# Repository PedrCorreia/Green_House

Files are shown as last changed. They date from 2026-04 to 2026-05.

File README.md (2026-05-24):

# LoRaWAN Greenhouse Environmental Monitoring System

**Group 34346** — DTU IoT Project

Distributed IoT system for real-time greenhouse environmental monitoring using LoRa/LoRaWAN wireless communication over ESP32-based sensor nodes.

**Languages & Technologies:** C/C++ | Python | JavaScript | KiCad | Arduino

---

## System Overview

Multi-node greenhouse monitoring network with dual LoRa communication paths.

### Node Architecture
```
5 ESP32-based Nodes:
  • Sensor Node (LoRa P2P telemetry)
  • LoRaWAN Sensor Node (Cibicom OTAA uplink)
  • Gateway (WiFi/MQTT bridge + LoRa P2P RX)
  • Gateway Slave (LoRaWAN serial bridge)
  • Light Control Node (LoRa P2P receiver)
```

### Monitored Parameters
| Parameter | Sensor | Range |
|---|---|---|
| Temperature & Humidity | DHT22 | -40…+85°C, 0-100% |
| Soil Moisture | Capacitive | 0-100% |
| Light Intensity | KY-018 | 0-4095 lux |
| Battery Voltage | ADC | 0-5000 mV |

### Technology Stack
| Component | Technology |
|---|---|
| Microcontroller | ESP32 DevKit V1 |
| Radio Module | RN2483 LoRa |
| Power Management | AP2112K-3.3 LDO, AO3401A MOSFET |
| PCB Design | KiCad 10.0.0 |
| Communications | LoRa P2P, LoRaWAN (OTAA), WiFi, MQTT |

---

## Firmware Targets

| Target | Language | File | Purpose |
|---|---|---|---|
| Sensor Node | C++ | sensor-node.ino | DHT22/soil/light telemetry over LoRa P2P |
| LoRaWAN Sensor | C++ | lorawan-sensor-node.cpp | OTAA uplink to Cibicom/Loriot |
| Gateway | C++ | gateway.cpp | WiFi/MQTT bridge, LoRa P2P receiver |
| Gateway Slave | C++ | gateway-slave.cpp | LoRaWAN serial bridge |
| Light Node | C++ | light-node.ino | LoRa P2P command receiver for LED control |
| Backend Router | Python | loriot_router.py | 

---

## Communication Architecture

### Primary Path (LoRa P2P)
```
Sensor Node ──LoRa P2P──→ Gateway ──WiFi──→ MQTT Broker ──JSON──→ Dashboard
```

### Secondary Path (LoRaWAN)
```
LoRaWAN Sensor ──LoRaWAN──→ Cibicom/Loriot ──Webhook──→ Router ──MQTT──→ Dashboard
```
---

## Documentation

Individual README files in each directory contain hardware pinouts, configuration details, testing procedures, and troubleshooting.

**References:**
- [RN2483 Datasheet](https://ww1.microchip.com/downloads/en/DeviceDoc/40001811G.pdf)
- [ESP32 Arduino Core](https://github.com/espressif/arduino-esp32)
- [Cibicom LoRaWAN](https://iotnet.teracom.dk)
- [MQTT Protocol](https://mqtt.org)
- [Communication Flowchart](COMMUNICATION_FLOWCHART.md)
- [Hardware Schematics](hardware/)
- [Test Results](test/README.md)

---

**Last Updated:** May 2026 | **Status:** Ready for Submission | **Contact:** Group 34346

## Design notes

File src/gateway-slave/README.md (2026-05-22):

# ESP32 Gateway-Slave - LoRaWAN Cloud Bridge

## Table of Contents
1. [System Overview](#system-overview)
2. [Hardware Architecture](#hardware-architecture)
3. [Integration with Main Gateway](#integration-with-main-gateway)
4. [Data Structures](#data-structures)
5. [Execution Flow](#execution-flow)
6. [Methods Reference & Execution Order](#methods-reference--execution-order)
7. [Communication Protocols](#communication-protocols)
8. [Setup & Deployment](#setup--deployment)

---

## System Overview

### Purpose
The **Gateway-Slave** is an optional secondary ESP32 board that bridges LoRaWAN (cloud uplink) with the main gateway's P2P LoRa network. It acts as both:
1. **LoRaWAN relay**: Sends sensor data to Loriot/cloud backend
2. **P2P relay**: Forwards P2P LoRa packets back to main gateway via UART2

### Key Responsibilities
- **LoRaWAN Uplink**: Maintains persistent connection to Loriot cloud via OTAA join
- **Frequency Management**: Receives sleep/frequency commands from main gateway over UART2
- **P2P Passthrough**: Listens on same 868.1 MHz frequency as main network, forwards received packets to main gateway
- **Always-On Design**: Powered externally (USB), never sleeps; runs alongside main gateway

### When to Use
- **Extended range**: LoRaWAN coverage reaches areas P2P doesn't
- **Redundancy**: Sensor nodes can reach either gateway or relay through this one
- **Cloud uplinks**: Send data to Loriot, TTN, or other LoRaWAN network servers
- **Frequency monitoring**: Main gateway can command slave to change TX intervals from cloud

---

## Hardware Architecture

### Main Components

#### **ESP32 Microcontroller (Slave)**
- **Role**: Secondary control board dedicated to LoRaWAN
- **Power**: Externally powered (USB or AC adapter, does not sleep)
- **UART Ports**:
  - **UART1** (pins 16/17): Connected to RN2483 LoRaWAN module at 57600 baud
  - **UART2** (pins 18/19): Connected to main gateway for command/data bridge at 115200 baud
  - **UART0** (USB): USB Serial for debugging at 115200 baud

#### **RN2483 LoRa Module (Slave - LoRaWAN)**
- **Communication**: Connected via UART1 at 57600 baud
- **Protocol**: LoRaWAN Class A (OTAA join)
- **Network**: Loriot backend (cibicom.net) EU868 cluster
- **Purpose**: Cloud uplink for sensor data and downlink reception
- **Interface**: AT command protocol (via rn2xx3 library)
  - Commands: `sys get hweui`, `mac join otaa`, `mac tx ucnf`, etc.
  - Responses: `ok`, `accepted`, `mac_tx_ok`, `mac_rx <port> <hex>`, etc.

### Pin Mapping

```
ESP32 (Gateway-Slave) UART Connections:
├─ UART1 (LoRaWAN):
│  ├─ GPIO16 (RX) <- RN2483 TX
│  └─ GPIO17 (TX) -> RN2483 RX
├─ UART2 (Main Gateway Bridge):
│  ├─ GPIO18 (RX) <- Main Gateway GPIO19 (TX)
│  └─ GPIO19 (TX) -> Main Gateway GPIO18 (RX)
├─ GPIO23: RN2483 Reset (active-low)
├─ GPIO2: LED (status indicator)
└─ UART0 (USB Serial @ 115200):
   └─ Used for Serial.print() debugging

Baud Rates:
├─ UART1: 57600 (RN2483 standard for LoRaWAN)
├─ UART2: 115200 (slave bridge, higher speed for reliability)
└─ USB Serial: 115200 (debugging)
```

### Integration Point: Main Gateway ↔ Slave

```
Main Gateway GPIO19 (TX @ 115200)  →  Slave GPIO18 (RX)
Main Gateway GPIO18 (RX @ 115200)  ←  Slave GPIO17 (TX)

(Plus GND shared)
```

---

## Integration with Main Gateway

### Dual-Mode Operation

The slave simultaneously operates in two modes:

#### **Mode 1: LoRaWAN Class A Uplink (Primary)**
```
Slave RN2483 ← LoRaWAN network @ 868.1 MHz
    ↓
Joined to Loriot backend (OTAA credentials)
    ↓
Transmit 13-byte sensor payload on port 2
    ↓
Receive Class A downlink (1 sec after TX)
    ↓
Parse frequency/command, update sleep interval
    ↓
Acknowledge via UART2 to main gateway
```

#### **Mode 2: P2P Relay Passthrough (Secondary)**
```
Slave RN2483 also listens on 868.1 MHz in P2P mode
    ↓
Receives encrypted sensor packets from nodes
    ↓
Forward raw hex payload to main gateway via UART2
    ↓
Main gateway parses, validates, publishes to MQTT
```

### UART2 Command Protocol

**Main Gateway → Slave** (115200 baud, one command per line):
```
FREQ:<uint16>\n
  Example: "FREQ:120\n"
  Meaning: Set LoRaWAN TX interval to 120 seconds
  Response: "OK\n" or "ERR\n"

POLL\n
  Meaning: Send a poll uplink to receive queued downlinks
  Response: "OK\n" or "ERR\n"
```

**Slave → Main Gateway** (115200 baud):
```
<hex_payload>\n
  Example: "A5014947503030D2FFAA55...\n"
  Meaning: Forward P2P LoRa packet (13 bytes, hex encoded)
  Action: Main gateway parses as SensorData, publishes to MQTT

OK\n
  Meaning: Command (FREQ or POLL) was accepted

ERR\n
  Meaning: Join not established or TX failed
```

### Information Flow

```
MINUTE 0:00 ─ Main Gateway PING ────────────────────────
    ├─ Gateway: sendPing("scheduled")
    └─ Broadcast 8-byte PING on 868.1 MHz

MINUTE 0:00 ─ Slave Receives PING ──────────────────────
    ├─ Slave RN2483 in P2P RX mode
    ├─ Detects broadcast (P2P, not addressed)
    └─ (Ignores or logs for debugging)

MINUTE 0:04 ─ Slave Sends LoRaWAN Uplink ──────────────
    ├─ Slave: mac tx ucnf 2 <hex_payload>
    ├─ RN2483 transmits LoRaWAN packet to Loriot
    └─ Main gateway: sendToSlave("FREQ:118")
       ├─ Slave receives command via UART2
       ├─ Parses "FREQ:118"
       └─ Responds: "OK\n"

MINUTE 0:05 ─ Slave Receives Class A Downlink ─────────
    ├─ 1 second after LoRaWAN TX
    ├─ Loriot sends queued command (frequency update)
    ├─ Slave parses downlink port + payload
    └─ Slave responds to main gateway via UART2
       └─ Forwards parsed frequency if needed

MINUTE 2:00 ─ Cycle Repeats ────────────────────────────
    └─ Next PING / LoRaWAN TX
```

---

## Data Structures

### Sensor Data (13 bytes, from P2P relay)

**Received from gateway as hex string via UART2**:
```
<hex_payload>\n
Format: 26 hex characters = 13 bytes (same as main sensor-node format)

Structure:
Byte 0-3:   Device ID (0x01AABBCC for sensor nodes)
Byte 4-5:   Temperature (int16_t / 10)
Byte 6:     Humidity
Byte 7-8:   Lux
Byte 9-10:  Soil Moisture
Byte 11:    Water Leak
Byte 12:    Battery

Encryption: XOR with SHARED_KEY (same key as main gateway)
```

### LoRaWAN Uplink Packet

**13 bytes, port 2**:
```
[Device ID: 4B] [Temperature: 2B] [Humidity: 1B] [Lux: 2B] 
[Soil: 2B] [Leak: 1B] [Battery: 1B]

Encryption: LoRaWAN AppSKey + NwkSKey (hardware AES)
```

### LoRaWAN Downlink Packet (Class A)

**Received from Loriot, port varies**:
```
Port 2:  Frequency/sleep interval (2 bytes, big-endian)
  Example: [0x00, 0x78] = 120 seconds next TX interval
  
Custom Port: Other cloud commands as needed

Decryption: Automatic (RN2483 library handles LoRaWAN crypto)
```

### UART2 Command Packet

```
Command: "FREQ:<uint16>\n"
  Example: "FREQ:120\n" (11 bytes + newline)

Response: "OK\n" (3 bytes) or "ERR\n" (4 bytes)

Data Packet: "<hex_string>\n"
  Example: "A5014947503030D2FFAA55...\n" (27 bytes + newline)
```

---

## Execution Flow

### Boot Sequence

```
main() [Arduino startup]
  ↓
setup()
  ├─ Initialize Serial (115200 USB debug)
  ├─ Initialize GPIO (LED, reset pin)
  ├─ connectToLoRa()
  │  ├─ Reset RN2483 (GPIO23 pulse)
  │  ├─ Begin UART1 @ 57600 baud
  │  ├─ Get hardware EUI ("sys get hweui")
  │  └─ Print EUI to Serial (for Loriot registration)
  ├─ joinLoRaWAN()
  │  ├─ Set APPEUI and APPKEY (from code defines)
  │  ├─ Attempt "mac join otaa"
  │  ├─ Wait for acceptance (up to 10 seconds)
  │  └─ If success: set loraReady = true
  ├─ Initialize UART2 @ 115200 for main gateway bridge
  ├─ Initialize timing variables
  └─ Print "Slave ready"

[Loop begins]
```

### Main Loop (continuous)

```
loop() [runs thousands of times per second]
  ├─ readUart2FromGateway()
  │  └─ If line received:
  │     ├─ Check if "FREQ:<uint16>"
  │     │  ├─ Parse frequency/interval
  │     │  ├─ Update txIntervalMs
  │     │  └─ Respond: "OK\n"
  │     └─ Check if hex payload (P2P relay)
  │        ├─ Forward to main gateway later
  │        └─ Skip (main handles parsing)
  │
  ├─ readUart2PayloadsFromGateway()
  │  └─ Buffer P2P sensor packets for cloud uplink
  │
  ├─ manageLoRaWANTx()
  │  └─ If txIntervalMs elapsed:
  │     ├─ Build 13-byte payload
  │     ├─ Call sendLoRaData()
  │     │  ├─ mac tx ucnf 2 <hex>
  │     │  └─ Wait for "mac_tx_ok"
  │     └─ Listen for Class A downlink (1 sec)
  │        └─ readLoRaLine() to capture downlink
  │
  ├─ sendToGateway()
  │  └─ Forward P2P payloads to main gateway via UART2
  │
  └─ handleLed()
     └─ Blink LED to indicate activity
```

---

## Methods Reference & Execution Order

### **Phase 1: Initialization Functions** (called in `setup()`)

#### 1. `connectToLoRa()`
- **Purpose**: Initialize RN2483 LoRaWAN module with UART and reset
- **Called**: Once during setup
- **Parameters**: None
- **Flow**:
  1. Set GPIO23 (RN2483 reset pin) to HIGH
  2. Begin UART1 @ 57600 baud
  3. Pulse reset LOW → HIGH (hardware reset)
  4. Flush serial buffer
  5. Read banner from RN2483
  6. Get hardware EUI via "sys get hweui"
  7. Print EUI to Serial (user must register this on Loriot)
- **Returns**: void

#### 2. `joinLoRaWAN()`
- **Purpose**: Perform OTAA join to Loriot LoRaWAN network
- **Called**: Once during setup (critical for cloud uplink)
- **Parameters**: None
- **Flow**:
  1. Call rn2xx3 library to set APPEUI and APPKEY (from defines)
  2. Send "mac join otaa" command
  3. Wait for "accepted" response (up to 10 seconds)
  4. If joined: set loraReady = true, print success
  5. If timeout: print error, attempt retry in loop
- **Returns**: bool (true = joined, false = failed)
- **Critical**: Device must be registered on Loriot before join succeeds

---

### **Phase 2: Main Loop Functions** (called repeatedly in `loop()`)

#### 3. `readUart2FromGateway()`
- **Purpose**: Listen for commands from main gateway over UART2
- **Called**: Every loop iteration
- **Parameters**: None
- **Flow**:
  1. If slaveSerial.available():
     - Read line until '\n'
     - Check if "FREQ:<uint16>"
       - Parse interval, update txIntervalMs
       - Respond: "OK\n"
     - Else if hex string (P2P relay)
       - Buffer for later forwarding
- **Returns**: void

#### 4. `manageLoRaWANTx()`
- **Purpose**: Periodically send LoRaWAN uplinks at configured interval
- **Called**: Every loop iteration
- **Parameters**: None
- **Flow**:
  1. Check if txIntervalMs elapsed since lastTxMs
  2. If yes:
     - Build 13-byte sensor payload (or mock data)
     - Call sendLoRaData()
       - mac tx ucnf 2 <hex_payload>
       - Wait for "mac_tx_ok"
     - Update lastTxMs = millis()
     - Listen for Class A downlink (1 second window)
- **Returns**: void

#### 5. `sendLoRaData()`
- **Purpose**: Transmit LoRaWAN uplink packet
- **Called**: By manageLoRaWANTx()
- **Parameters**: None (uses global payload buffer)
- **Flow**:
  1. Convert payload to hex string
  2. Send command: "mac tx ucnf 2 <hex>"
  3. Wait for response (should be "ok" then "mac_tx_ok")
  4. Log to Serial
- **Returns**: bool (true = TX accepted, false = failed)

#### 6. `sendToGateway(const String& msg)`
- **Purpose**: Send data or acknowledgment back to main gateway over UART2
- **Called**: After processing commands or forwarding P2P packets
- **Parameters**: msg (response string)
- **Flow**:
  1. Print to slaveSerial
  2. Print newline
  3. Echo to Serial for debugging
- **Returns**: void

---

### **Phase 3: UART2 Bridge Functions**

#### 7. `handleSerialInput()`
- **Purpose**: Read commands from main gateway and process them
- **Called**: Every loop iteration
- **Parameters**: None
- **Flow**:
  1. While slaveSerial.available():
     - Read line until '\n'
     - Trim whitespace
     - Check if "FREQ:120" format
       - Extract uint16_t value
       - Update txIntervalMs
       - Respond "OK\n"
     - Else if hex string
       - Forward to gateway (or ignore if P2P relay)
- **Returns**: void

#### 8. `relayP2PPacket(const String& hexPayload)`
- **Purpose**: Forward P2P LoRa packet from slave's RN2483 back to main gateway
- **Called**: If slave RN2483 receives P2P packet while in RX mode
- **Parameters**: hexPayload (26-char hex string)
- **Flow**:
  1. Send to gateway via sendToGateway()
  2. Main gateway receives, parses as SensorData
  3. Main gateway publishes to MQTT
- **Returns**: void

---

### **Phase 4: LoRaWAN Management Functions**

#### 9. `readLoRaLine(int timeoutMs)`
- **Purpose**: Read one line of text from RN2483 (blocking until '\n' or timeout)
- **Called**: By sendLoRaData() and downlink listeners
- **Parameters**: timeoutMs (maximum time to wait)
- **Flow**:
  1. Initialize timer and empty String
  2. While millis() < timeout:
     - If loraSerial.available():
       - Read char
       - Skip '\r'
       - If '\n', trim and return
       - Else append to line
     - Delay 1ms
  3. If timeout, return whatever accumulated (possibly empty)
- **Returns**: String (one line of text, or empty if timeout)

#### 10. `flushLoRaInput()`
- **Purpose**: Clear any pending data in LoRa serial buffer
- **Called**: Before RX mode or after TX
- **Parameters**: None
- **Flow**:
  1. While loraSerial.available(): read and discard
- **Returns**: void

#### 11. `parseFrequencyCommand(const String& cmd)`
- **Purpose**: Extract uint16_t sleep interval from "FREQ:120" format
- **Called**: By handleSerialInput()
- **Parameters**: cmd (e.g., "FREQ:120")
- **Flow**:
  1. Find ':' delimiter
  2. Extract substring after ':'
  3. Convert to uint16_t
  4. Validate range (MIN_TX_INTERVAL_MS to MAX_TX_INTERVAL_MS)
  5. Return parsed value
- **Returns**: uint16_t (interval in seconds, or 0 if invalid)

---

### **Phase 5: Utility Functions**

#### 12. `bytesToHex(const uint8_t* data, size_t len)`
- **Purpose**: Convert byte array to hex string
- **Called**: By sendLoRaData()
- **Parameters**:
  - data: input byte array
  - len: number of bytes
- **Flow**:
  1. For each byte:
     - Convert high nibble to hex char
     - Convert low nibble to hex char
     - Append both to output String
  2. Return uppercase hex string
- **Returns**: String (hex representation)

#### 13. `hexToBytes(const String& hexStr, uint8_t* out, size_t outLen)`
- **Purpose**: Convert hex string to byte array
- **Called**: By payload parsing functions
- **Parameters**:
  - hexStr: hex string (e.g., "A5014947503030D2")
  - out: output byte array
  - outLen: size of output array
- **Flow**:
  1. Validate hexStr.length() == outLen * 2
  2. For each pair of hex chars:
     - Convert to nibbles (0-15)
     - Combine: byte = (high << 4) | low
  3. Return true if success
- **Returns**: bool

#### 14. `setLed(bool on)`
- **Purpose**: Turn slave LED on/off (GPIO2)
- **Called**: To indicate activity or status
- **Parameters**: on (true = LED on, false = LED off)
- **Flow**:
  1. digitalWrite(LED_PIN, on ? HIGH : LOW)
  2. Log to Serial
- **Returns**: void

---

## Communication Protocols

### UART1: RN2483 LoRaWAN Module (57600 baud)

#### LoRaWAN AT Command Format
```
Request (Slave → RN2483):
  <command>\r\n
  Example: "mac tx ucnf 2 A50149474F50\r\n"

Response (RN2483 → Slave):
  <response>\r\n
  Examples:
    "ok\r\n"           (command accepted)
    "accepted\r\n"     (join successful)
    "mac_tx_ok\r\n"    (TX complete)
    "mac_rx 2 A50149...\r\n"  (downlink received on port 2)
    "invalid_param\r\n" (error)
```

#### Common Commands
```
Initialization:
  sys get hweui           → Returns hardware EUI (register on Loriot)
  mac set deveui <id>     → Set device EUI (usually not needed for OTAA)
  
Credentials:
  mac set appeui <hex>    → Application EUI (16 hex chars)
  mac set appkey <hex>    → Application Key (32 hex chars)
  
OTAA Join:
  mac join otaa           → Initiate join request
  Response: "ok" (sent), later "accepted" or timeout
  
Transmission:
  mac tx ucnf 2 <hex>     → Send unconfirmed uplink on port 2
  mac tx cnf 2 <hex>      → Send confirmed uplink (waits for ACK)
  
  Response: "ok" (accepted), then:
    "mac_tx_ok"  (TX complete, uplink sent)
    or
    "mac_err"    (TX failed)
  
  1 second after TX: Class A receive window opens
    "mac_rx 2 <hex>"  (if downlink received)
    or (no downlink)
```

### UART2: Main Gateway Bridge (115200 baud)

#### Command Protocol
```
Main Gateway → Slave:
  <command>\n

  FREQ:<uint16>\n
    Example: "FREQ:120\n"
    Meaning: Set LoRaWAN TX interval to 120 seconds
    Response: "OK\n" or "ERR\n"

  POLL\n
    Meaning: Send a poll uplink (receive-only, no data)
    Response: "OK\n" or "ERR\n"

Slave → Main Gateway:
  <response>\n

  OK\n               Command acknowledged
  ERR\n              Error (join failed, TX failed, etc.)
  <hex_payload>\n    P2P relay packet (13 bytes, hex encoded)
                    Example: "A5014947503030D2FFAA55...\n"
```

#### Typical Exchange
```
Main → Slave: "FREQ:120\n"
Slave → Main: "OK\n"
[Later, LoRaWAN TX happens]
Slave → Main: "<hex_payload>\n" (if P2P packet received)
Main → Slave: "POLL\n"
Slave → Main: "OK\n"
```

---

## Setup & Deployment

### Prerequisites

#### Credentials from Loriot
1. **Register device on Loriot (iotnet.teracom.dk)**:
   - Select "OTAA" mode
   - Click "Generate all except DevEUI"
   - Copy APPEUI (16 hex chars)
   - Copy APPKEY (32 hex chars)

2. **Flash slave, retrieve hardware EUI from Serial Monitor**:
   ```
   Slave starting...
   RN2483 connected.
   Hardware EUI: 70B3D5xxxxxxxx
   [Copy this value]
   ```

3. **Enter Hardware EUI on Loriot**:
   - On device page, fill in Hardware EUI field
   - Device is now registered and ready to join

#### Libraries Required
```
Arduino IDE → Sketch → Include Library → Manage Libraries

Install:
  - rn2xx3 (by Ideetron) - LoRaWAN library
  - HardwareSerial (built-in)
  - Arduino core libraries
```

### Configuration

**File**: [gateway-slave/gateway-slave.cpp](gateway-slave.cpp) (lines 33-35)

```cpp
static const char* APPEUI = "0123456789ABCDEF";  // 16 hex chars from Loriot
static const char* APPKEY = "0123456789ABCDEF0123456789ABCDEF";  // 32 hex chars

#define DEFAULT_TX_INTERVAL_MS 30000UL  // 30 seconds between uplinks
```

### Flashing Procedure

```
Board: ESP32 Dev Module
Upload Speed: 921600
Port: COM[your device]
File: gateway-slave/gateway-slave.cpp
```

### Verification

**Serial Monitor Output** (115200 baud):
```
Slave starting...
RN2483 connected.
Hardware EUI: 70B3D5XXXXXXXX
Attempting LoRaWAN join...
[Waiting for "accepted"...]
LoRaWAN joined successfully!
Slave ready.
[Every 30 seconds]
Sending LoRaWAN uplink on port 2...
TX complete.
Listening for Class A downlink...
```

**Main Gateway Integration**:
```
Gateway Serial:
  <- Slave: OK
  <- Slave: A5014947503030D2FFAA55... (P2P relay)
  
Main gateway publishes to MQTT:
  {"type":"sensorData","deviceId":"0x01AABBCC",...}
```

---

## Summary

The **Gateway-Slave** extends the greenhouse monitoring system to cloud platforms by:

| Aspect | Detail |
|---|---|
| **Primary Role** | LoRaWAN uplink bridge to Loriot |
| **Secondary Role** | P2P relay for extended coverage |
| **Power** | Externally powered (always-on) |
| **Communication** | UART1 to RN2483, UART2 to main gateway |
| **Timing** | LoRaWAN TX every 30-3600 seconds (configurable) |
| **Security** | LoRaWAN AES encryption (automatic) |

**Key Functions**:
1. OTAA join to Loriot LoRaWAN network
2. Periodic uplink with 13-byte sensor data
3. Receive Class A downlinks (frequency/sleep updates)
4. Forward P2P packets from main network to cloud
5. UART2 bridge for gateway coordination

**Integration Points**:
- Main Gateway sends commands via UART2 ("FREQ:120\n")
- Slave sends acknowledgments ("OK\n")
- Slave forwards P2P packets for MQTT publication
- Slave's LoRaWAN uplinks provide redundant cloud connectivity

See [Main Gateway Documentation](../gateway/README.md) for system-wide architecture.

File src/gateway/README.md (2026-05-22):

# ESP32 Gateway - Comprehensive Technical Documentation

## Table of Contents
1. [System Overview](#system-overview)
2. [Hardware Architecture](#hardware-architecture)
3. [Integration with Other Nodes](#integration-with-other-nodes)
4. [Data Structures](#data-structures)
5. [Execution Flow](#execution-flow)
6. [Methods Reference & Execution Order](#methods-reference--execution-order)
7. [Communication Protocols](#communication-protocols)
8. [Security & Obfuscation](#security--obfuscation)

---

## System Overview

### Purpose
The **Gateway** is the central hub of the Greenhouse monitoring system. It sits on WiFi and MQTT, acting as a bridge between remote sensor nodes (communicating via LoRa P2P radio) and a cloud MQTT dashboard. It also manages a secondary board (gateway-slave) that handles LoRaWAN uplinks to cloud infrastructure.

### Key Responsibilities
- **WiFi/MQTT Connectivity**: Maintains persistent WiFi connection and MQTT broker link for dashboard communication
- **Sensor Pinging**: Periodically wakes sensor nodes via LoRa broadcast pings (every 2 minutes)
- **Data Reception**: Listens for sensor node replies containing environmental data (temperature, humidity, lux, soil moisture, water leak, battery)
- **MQTT Publishing**: Publishes received sensor data as JSON to the MQTT broker for dashboard visualization
- **Light Control**: Computes when plants need supplemental light based on ambient lux levels and sends control commands back to nodes
- **Slave Coordination**: Bridges commands and sensor data with a secondary gateway-slave board via UART2
- **Always-On Design**: Gateway never sleeps; it maintains 24/7 connectivity and is powered externally

---

## Hardware Architecture

### Main Components

#### **ESP32 Microcontroller (Main Gateway)**
- **Role**: Central control board with WiFi and MQTT stack
- **Power**: Externally powered (does not sleep)
- **UART Ports**:
  - **UART1** (pins 16/17): Connected to RN2483 LoRa module for P2P radio with sensor nodes
  - **UART2** (pins 18/19): Connected to gateway-slave ESP32 board
  - **UART0** (USB): USB Serial for debugging and manual testing

#### **RN2483 LoRa Module (Main Gateway)**
- **Communication**: Connected via UART1 at 57600 baud
- **Protocol**: LoRa P2P (not LoRaWAN)
- **Frequency**: 868.1 MHz (European ISM band)
- **Purpose**: Raw LoRa radio with sensor nodes using proprietary packet format
- **Interface**: AT command protocol
  - Commands: `radio tx`, `radio rx`, `radio set`, `mac pause`, `sys get ver`
  - Responses: `ok`, `radio_tx_ok`, `radio_rx <hex_payload>`, `radio_err`, etc.

#### **ESP32 Microcontroller (Gateway-Slave)**
- **Role**: Secondary board dedicated to LoRaWAN protocol
- **Connection**: UART2 bridge from main gateway (pins 18→16 RX, 19→17 TX)
- **Purpose**: Separate LoRaWAN stack for cloud uplinks; main gateway bridges frequency commands and receives parsed sensor data
- **Power**: Can sleep independently

#### **RN2483 LoRa Module (Gateway-Slave)**
- **Communication**: Connected via UART1 at 57600 baud
- **Protocol**: LoRaWAN (Class A)
- **Purpose**: Cloud bridge for deeper coverage using Loriot or similar LoRaWAN network

### Pin Mapping

```
ESP32 (Main Gateway) UART Connections:
├─ UART1 (LoRa P2P):
│  ├─ GPIO16 (RX) <- RN2483 TX
│  └─ GPIO17 (TX) -> RN2483 RX
├─ UART2 (Slave Bridge):
│  ├─ GPIO18 (RX) <- ESP32 Slave GPIO17 (TX)
│  └─ GPIO19 (TX) -> ESP32 Slave GPIO16 (RX)
├─ GPIO2: RN2483 Reset (active-low)
├─ GPIO4: LED (status indicator)
└─ UART0 (USB Serial @ 115200):
   └─ Used for Serial.print() debugging

Baud Rates:
├─ UART1: 57600 (RN2483 standard)
├─ UART2: 115200 (slave bridge, faster for reliability)
└─ USB Serial: 115200 (debugging)
```

---

## Integration with Other Nodes

### System Architecture Diagram

```
                          Internet / MQTT Broker (broker.emqx.io)
                                    ↑
                                    | WiFi + MQTT
                                    |
    ┌─────────────────────────────────────────────────────────┐
    │  ESP32 Gateway (Main Board)                             │
    │  ├─ WiFi (receives commands, publishes sensor data)     │
    │  ├─ MQTT (subscriptions: ping, control; topic: status) │
    │  ├─ UART1 ← RN2483 LoRa P2P (868.1 MHz)                │
    │  └─ UART2 ← Gateway-Slave (LoRaWAN bridge)             │
    └────┬────────────────────────────────┬──────────────────┘
         │ LoRa P2P @ 868.1 MHz           │ UART2 @ 115200
         │ (Proprietary protocol)         │
         │                                │
    ┌────▼──────────────────┐      ┌────▼──────────────────────┐
    │ Sensor Nodes          │      │ ESP32 Gateway-Slave       │
    │ (Multiple instances)  │      │ ├─ LoRaWAN Class A        │
    │ ├─ Node 0x01AABBCC   │      │ ├─ RN2483 LoRaWAN         │
    │ ├─ Node 0x02CCDDEE   │      │ ├─ Loriot Cloud Bridge    │
    │ └─ ...                │      │ └─ Receives sleep/freq cmds│
    └───────────────────────┘      └───────────────────────────┘
           ↑                               ↑
           │ 13-byte encrypted            │ LoRaWAN
           │ sensor payloads              │ Uplink
           │                              │
```

### Sensor Node Integration

#### **Wake-Up Flow**
1. **Scheduled Ping** (every 2 minutes):
   - Gateway sends 8-byte broadcast PING packet (`0x50 0x49 0x4E 0x47` + 4-byte SHARED_KEY)
   - Encrypted with XOR to prevent rogue nodes

2. **Node Reception**:
   - Sensor node's RN2483 receives the ping
   - Node wakes from sleep upon radio interrupt
   - Node checks packet validity (XOR obfuscation)

3. **Sensor Data TX**:
   - Node collects temperature, humidity, lux, soil moisture, water leak, battery voltage
   - Packages into 13-byte binary struct, XOR encrypts with SHARED_KEY
   - Transmits 26-char hex string via LoRa back to gateway within ~3 seconds (BOOT_OVERHEAD_MS)

#### **Data Reception Flow**
1. **Post-Ping Listen Window** (10 seconds):
   - Gateway enters RX mode after transmitting ping
   - Listens for `radio_rx <hex>` response from RN2483

2. **Payload Parsing**:
   - Convert 26-char hex string to 13 bytes
   - XOR decrypt with SHARED_KEY
   - Extract device ID (4 bytes), temperature (2 bytes, /10), humidity, lux, soil moisture, water leak, battery

3. **Validation**:
   - Verify device ID is in APPROVED_DEVICE_IDS whitelist
   - Reject if unknown node (security & noise filtering)

4. **MQTT Publication**:
   - JSON format: `{"type":"sensorData", "deviceId":"0x01AABBCC", "temperature":23.5, "humidity":65, "lux":150, ...}`
   - Published to `esp32/myroom123/status`

#### **Light Control Flow**
1. **Lux Threshold Check**:
   - If received lux < 200 (LIGHT_THRESHOLD_LUX), plant needs light
   - If lux >= 200, light is adequate

2. **Send Light Command**:
   - If light needed: send 8-byte command to sensor node with `desiredLux=500`, `nextSleepSeconds` (calculated)
   - If light adequate: send sync-only command (no supplemental light)

3. **Node Response**:
   - Node receives command, schedules next wake-up time
   - Sensor node stays awake longer if lux control active
   - Sensor node calculates new sleep interval

### Gateway-Slave Integration (LoRaWAN Bridge)

#### **Slave Communication Protocol (UART2)**
```
Main Gateway ← UART2 → Gateway-Slave
Baud: 115200, Format: 8N1

Command Format (Main → Slave):
  "FREQ:<uint16>\n"      - Set LoRaWAN TX frequency (e.g., "FREQ:120\n")
  "SLEEP:<seconds>\n"    - Command sleep duration

Response Format (Slave → Main):
  "<hex_payload>\n"      - Forward received sensor data as hex string
  "ACK\n"                - Command acknowledged
  "ERR\n"                - Error response
```

#### **Slave Data Flow**
1. **Main gateway sends frequency command**:
   - Example: `sendToSlave("FREQ:120")` instructs slave to transmit LoRaWAN uplink on frequency 120
   - Slave receives command, updates LoRaWAN parameters, transmits uplink to cloud

2. **Slave forwards sensor data**:
   - If slave's RN2483 receives a LoRa P2P packet (same frequency, compatible modulation)
   - Slave forwards raw hex payload to main gateway via UART2
   - Main gateway parses as SensorData, publishes to MQTT (same as direct reception)
   - This allows extended coverage: sensors can talk to either gateway or relay through slave

---

## Data Structures

### SensorData (13 bytes)

```cpp
struct SensorData {
  uint32_t deviceId;      // 4 bytes: Unique sensor node identifier
  float    temperature;   // 2 bytes: Signed int16, divided by 10 (e.g., 235 = 23.5°C)
  uint8_t  humidity;      // 1 byte: 0-100%
  uint16_t lux;           // 2 bytes: Ambient light level (0-65535 lux)
  uint16_t soilMoisture;  // 2 bytes: Capacitive soil moisture reading
  bool     waterLeak;     // 1 byte: Boolean flag (any non-zero = true)
  uint8_t  battery;       // 1 byte: Battery percentage or raw ADC value (0-255)
};
```

**Binary Layout**:
```
Byte 0-3:  Device ID (big-endian uint32_t)
Byte 4-5:  Temperature (big-endian int16_t, /10)
Byte 6:    Humidity
Byte 7-8:  Lux (big-endian uint16_t)
Byte 9-10: Soil Moisture (big-endian uint16_t)
Byte 11:   Water Leak
Byte 12:   Battery
```

### PING Packet (8 bytes)

```cpp
uint8_t pingBuf[8] = {
  0x50, 0x49, 0x4E, 0x47,  // ASCII "PING" (header)
  0xA3, 0x7F, 0x2C, 0x91   // SHARED_KEY (obfuscation)
};
```

Before TX: XOR encrypted with SHARED_KEY (cycles: key[0], key[1], key[2], key[3], key[0]...)

### Light Command Packet (8 bytes)

```cpp
uint8_t lightCmd[8] = {
  // Byte 0-3: Target device ID (big-endian uint32_t)
  // Byte 4-5: Desired lux level (big-endian uint16_t, 0 if not needed)
  // Byte 6-7: Next sleep interval in seconds (big-endian uint16_t)
};
```

Before TX: XOR encrypted with SHARED_KEY

### Light Control Node Packet (5 bytes)

```cpp
uint8_t lightNodeCmd[5] = {
  // Byte 0-3: Light node device ID (e.g., 0x00000005)
  // Byte 4: Command (0x01 = ON, 0x00 = OFF)
};
```

Response (ACK): Same format with status in byte 4 (0x01 = OK, 0x00 = FAIL)

---

## Execution Flow

### Boot Sequence

```
main() [Arduino startup]
  ↓
setup()
  ├─ Initialize Serial (115200)
  ├─ Initialize GPIO (LED pin)
  ├─ connectToWiFi()
  │  ├─ WiFi.mode(WIFI_STA)
  │  ├─ WiFi.begin(SSID, PASSWORD)
  │  └─ Wait for connection (20 sec timeout)
  ├─ Initialize MQTT client
  │  ├─ setServer(broker.emqx.io, 1883)
  │  └─ setCallback(mqttCallback)
  ├─ initLoRa()
  │  ├─ Reset RN2483 (GPIO2)
  │  ├─ Begin UART1 @ 57600
  │  ├─ Get RN2483 version ("sys get ver")
  │  ├─ Pause MAC ("mac pause") to enable raw P2P mode
  │  └─ Configure 13 radio parameters (freq, SF, BW, power, CRC, etc.)
  ├─ Initialize Slave UART2 @ 115200
  ├─ Initialize timing variables (lastPingTime, lastHeartbeatTime)
  └─ Print "Gateway ready"

[Loop begins]
```

### Main Loop (runs every ~1-10ms)

```
loop() [continuous, called thousands of times per second]
  ├─ ensureWiFiConnected()
  │  └─ If disconnected, attempt WiFi.begin() every 5 sec
  ├─ If WiFi connected:
  │  ├─ If MQTT disconnected:
  │  │  └─ Retry MQTT every 3 sec (connectToMQTT)
  │  │     ├─ Connect to broker
  │  │     └─ Subscribe to topics (control, ping)
  │  └─ If MQTT connected:
  │     ├─ mqttClient.loop() [process incoming messages]
  │     └─ If 60 sec elapsed (HEARTBEAT_INTERVAL_MS):
  │        └─ publishHeartbeat() [send "Hello" + uptime to MQTT]
  ├─ If 120 sec elapsed (PING_INTERVAL_MS):
  │  └─ sendPing("scheduled") [wake all sensor nodes]
  ├─ handleSerialLightControlInput()
  │  └─ If USB Serial: '1' = turn on light, '0' = turn off (test shortcut)
  └─ handleSlaveSerial()
     └─ Read any responses from slave, parse & publish to MQTT
```

---

## Methods Reference & Execution Order

### **Phase 1: Initialization Functions** (called in `setup()`)

#### 1. `connectToWiFi()`
- **Purpose**: Establish initial WiFi connection
- **Called**: Once during setup
- **Parameters**: None (reads WIFI_SSID, WIFI_PASSWORD defines)
- **Flow**:
  1. Set WiFi mode to STA (Station)
  2. Call WiFi.begin() with credentials
  3. Wait up to 20 seconds for connection
  4. Print IP address if successful, or retry message
- **Returns**: void (no return value; uses global WiFi state)

#### 2. `initLoRa()`
- **Purpose**: Initialize RN2483 LoRa module with all radio parameters
- **Called**: Once during setup (critical; halts if fails)
- **Parameters**: None
- **Flow**:
  1. Set GPIO2 (RN2483 reset pin) to HIGH
  2. Begin UART1 @ 57600 baud
  3. Pulse reset low → high (hardware reset)
  4. Flush any stale serial data
  5. Read banner message from RN2483
  6. Get module version ("sys get ver")
  7. Send "mac pause" to disable LoRaWAN MAC
  8. Send 13 radio configuration commands:
     - `radio set mod lora` (mode)
     - `radio set freq 868100000` (frequency)
     - `radio set pwr 14` (transmit power)
     - `radio set sf sf12` (spreading factor)
     - `radio set afcbw 41.7` (AFC bandwidth)
     - `radio set rxbw 125` (RX bandwidth)
     - `radio set prlen 8` (preamble length)
     - `radio set crc on` (CRC enable)
     - `radio set iqi off` (IQ inversion)
     - `radio set cr 4/5` (coding rate)
     - `radio set wdt 60000` (watchdog timeout)
     - `radio set sync 12` (sync word)
     - `radio set bw 125` (bandwidth again)
  9. Return true if all commands return "ok", else false
- **Returns**: bool (true = ready, false = failed)
- **Critical**: If false, gateway halts (safety measure; broken radio means system cannot wake nodes)

---

### **Phase 2: Main Loop Functions** (called repeatedly in `loop()`)

#### 3. `ensureWiFiConnected()`
- **Purpose**: Maintain WiFi connection; retry if dropped
- **Called**: Every loop iteration
- **Parameters**: None
- **Flow**:
  1. Check WiFi.status() == WL_CONNECTED
  2. If connected, return immediately (no action)
  3. If disconnected and 5 sec elapsed since last retry:
     - Print "WiFi dropped"
     - Call WiFi.disconnect() then WiFi.begin() again
- **Returns**: void (no return; modifies global WiFi state)
- **Note**: Non-blocking; doesn't wait for connection

#### 4. `mqttClient.loop()`
- **Purpose**: Process incoming MQTT messages
- **Called**: Every loop iteration (if WiFi + MQTT connected)
- **Parameters**: None (calls registered callback)
- **Triggers**: mqttCallback() for messages on subscribed topics
- **Returns**: void

#### 5. `publishHeartbeat()`
- **Purpose**: Periodically send gateway status to MQTT (keep-alive)
- **Called**: Every 60 seconds (HEARTBEAT_INTERVAL_MS)
- **Parameters**: None
- **Flow**:
  1. Check if MQTT connected (safety check)
  2. Build JSON: "Hello from ESP32 | uptime: X | LED: ON/OFF"
  3. Publish to TOPIC_STATUS ("esp32/myroom123/status")
  4. Print to Serial
- **Returns**: void

#### 6. `handleSerialLightControlInput()`
- **Purpose**: Read manual light control commands from USB Serial (test shortcut)
- **Called**: Every loop iteration
- **Parameters**: None
- **Flow**:
  1. If Serial.available():
     - Read one character
     - If '1': sendLightControlCmd(true)
     - If '0': sendLightControlCmd(false)
- **Returns**: void
- **Note**: For testing only; remove when automatic light control verified

#### 7. `handleSlaveSerial()`
- **Purpose**: Read responses/data from gateway-slave over UART2
- **Called**: Every loop iteration
- **Parameters**: None
- **Flow**:
  1. While slaveSerial.available():
     - Read line until '\n'
     - Trim whitespace
     - Parse as hex payload
     - Call parseSensorPayload()
     - If valid, call publishSensorData() to MQTT
- **Returns**: void

---

### **Phase 3: WiFi/MQTT Functions** (event-driven, called from loop or callbacks)

#### 8. `connectToMQTT()`
- **Purpose**: Connect to MQTT broker and subscribe to topics
- **Called**: When MQTT disconnected and reconnect interval elapsed
- **Parameters**: None
- **Flow**:
  1. Check WiFi connected (safety check)
  2. Build unique client ID from ESP32 MAC address
  3. Call mqttClient.connect(clientId)
  4. If connected:
     - Subscribe to TOPIC_CONTROL ("esp32/myroom123/control")
     - Subscribe to TOPIC_PING ("esp32/myroom123/ping")
     - Publish connection message to TOPIC_STATUS
     - Return true
  5. If failed, print error code and return false
- **Returns**: bool (true = connected, false = failed)

#### 9. `mqttCallback(char* topic, byte* payload, unsigned int length)`
- **Purpose**: Handle incoming MQTT messages
- **Called**: Automatically by mqttClient.loop() when message arrives
- **Parameters**:
  - topic: string (e.g., "esp32/myroom123/ping")
  - payload: byte array (raw message data)
  - length: size of payload
- **Flow**:
  1. Convert payload bytes to String
  2. Print topic and message to Serial
  3. Check topic:
     - If TOPIC_PING ("esp32/myroom123/ping"):
       - If msg == "PING": call manualPingWithRetry()
       - Publish result to MQTT
     - If TOPIC_CONTROL ("esp32/myroom123/control"):
       - If msg == "ON" or "LIGHT ON": setLed(true), sendLightControlCmd(true)
       - If msg == "OFF" or "LIGHT OFF": setLed(false), sendLightControlCmd(false)
- **Returns**: void

#### 10. `publishStatus(const String& msg)`
- **Purpose**: Log status to Serial and publish to MQTT
- **Called**: From various functions (error/info reporting)
- **Parameters**: msg (status message string)
- **Flow**:
  1. Print to Serial ("STATUS: " + msg)
  2. If MQTT connected, publish to TOPIC_STATUS
- **Returns**: void

#### 11. `publishLightControlState()`
- **Purpose**: Publish current LED state to MQTT as JSON
- **Called**: When light state changes (sendLightControlCmd)
- **Parameters**: None
- **Flow**:
  1. Build JSON: `{"type":"LED", "deviceId":"0x00000005", "state":"ON"/"OFF"}`
  2. Print to Serial
  3. Publish to TOPIC_STATUS
- **Returns**: void

#### 12. `setLed(bool on)`
- **Purpose**: Turn gateway LED on/off (physical GPIO4 and state variable)
- **Called**: From mqttCallback or manual input
- **Parameters**: on (true = LED on, false = LED off)
- **Flow**:
  1. Set ledState variable
  2. digitalWrite(LED_PIN, on ? HIGH : LOW)
  3. Print status to Serial
- **Returns**: void

---

### **Phase 4: Slave Communication Functions**

#### 13. `sendToSlave(const String& cmd)`
- **Purpose**: Send command to gateway-slave board over UART2
- **Called**: When main gateway needs to instruct slave (e.g., frequency updates)
- **Parameters**: cmd (command string, e.g., "FREQ:120")
- **Flow**:
  1. Print command to slaveSerial
  2. Print newline
  3. Echo to Serial for debugging
- **Returns**: void

#### 14. `handleSlaveSerial()` (duplicate listing for reference)
- **See Phase 2, Function 7**

---

### **Phase 5: LoRa Radio Communication Functions**

#### 15. `sendLoRaCommand(const String& cmd, int timeoutMs)`
- **Purpose**: Send AT command to RN2483 and read response
- **Called**: During initLoRa() and when TX/RX packets
- **Parameters**:
  - cmd: AT command (e.g., "radio tx A50149474F50")
  - timeoutMs: how long to wait for response
- **Flow**:
  1. Print command to loraSerial
  2. Send "\r\n" terminator
  3. Call readLoRaLine(timeoutMs) to read response
  4. Print response to Serial
  5. Return response string
- **Returns**: String (response from RN2483)

#### 16. `readLoRaLine(int timeoutMs)`
- **Purpose**: Read one line of text from RN2483 (blocking until '\n' or timeout)
- **Called**: By sendLoRaCommand() and waitForSensorReply()
- **Parameters**: timeoutMs (maximum time to wait)
- **Flow**:
  1. Initialize timer and empty String
  2. While millis() < timeout:
     - If loraSerial.available():
       - Read char
       - Skip '\r' (carriage return)
       - If '\n', trim and return line
       - Else append to line
     - Delay 1ms (yield)
  3. If timeout, trim and return whatever accumulated (possibly empty)
- **Returns**: String (one line of text, or empty if timeout)

#### 17. `flushLoRaInput()`
- **Purpose**: Clear any pending data in LoRa serial buffer
- **Called**: During initLoRa() and before RX mode
- **Parameters**: None
- **Flow**:
  1. While loraSerial.available(): read and discard
- **Returns**: void

#### 18. `stopRx()`
- **Purpose**: Stop active RX listening on LoRa radio
- **Called**: If RX times out or error detected
- **Parameters**: None
- **Flow**:
  1. Send "radio rxstop\r\n" to RN2483
  2. Read up to 2 lines of response (drain buffer)
  3. Print to Serial
- **Returns**: void

---

### **Phase 6: Sensor Ping & Communication Functions** (core data flow)

#### 19. `sendPing(const char* reason)` 🎯 **CRITICAL**
- **Purpose**: Broadcast wake-up PING to all sensor nodes
- **Called**: Every 120 seconds (PING_INTERVAL_MS) or manually from MQTT
- **Parameters**: reason (string for logging, e.g., "scheduled" or "manual MQTT retry")
- **Flow**:
  1. Check loraReady (safety check)
  2. Build 8-byte PING packet: 0x50494E47 (ASCII "PING") + SHARED_KEY (4 bytes)
  3. Call bytesToHex() to convert to 26-char hex string
  4. Send command: "radio tx [hex]"
  5. Read response (should be "ok")
  6. If not "ok", log and return false
  7. Wait for "radio_tx_ok" (confirms TX complete, ~1-5 sec)
  8. Call waitForSensorReply(POST_PING_WAIT_MS = 10 sec)
  9. Return true if reply received, false if timeout/error
- **Returns**: bool (true = at least one sensor replied)

#### 20. `manualPingWithRetry()` 🎯 **CRITICAL**
- **Purpose**: Retry PING sequence when manually triggered via MQTT
- **Called**: From mqttCallback when "PING" message received on TOPIC_PING
- **Parameters**: None
- **Flow**:
  1. Save original lastPingTime (to restore if all retries fail)
  2. Loop for up to MANUAL_PING_TIMEOUT_MS (150 sec total):
     - Call sendPing("manual MQTT retry")
     - If success, return true immediately
     - If failed, wait RETRY_INTERVAL_MS (15 sec) before next attempt
     - Repeat
  3. If timeout reached, restore original lastPingTime and return false
- **Returns**: bool (true = got reply within 150 sec, false = all retries expired)

#### 21. `waitForSensorReply(int timeoutMs)` 🎯 **CRITICAL**
- **Purpose**: Enter RX mode and listen for sensor node reply
- **Called**: By sendPing() after broadcasting PING
- **Parameters**: timeoutMs (listen window, typically 10 sec)
- **Flow**:
  1. Send "radio rx 0" command (0 = listen until packet or watchdog)
  2. If not "ok", return false
  3. Call readLoRaLine(timeoutMs) to wait for response
  4. Check response:
     - If "radio_rx [hex]":
       - Extract hex payload
       - Convert hex string to 13 bytes (hexToBytes)
       - XOR decrypt with SHARED_KEY (xorWithKey)
       - Parse into SensorData struct (parseSensorPayload)
       - Validate device ID in whitelist (isApprovedDevice)
       - If invalid, reject and return false
       - If valid:
         - Calculate if light needed (lux < 200?)
         - Calculate nextSleepSeconds
         - Call publishSensorData() to MQTT
         - Delay LIGHT_CMD_PRE_DELAY_MS (400ms) for RX turnaround
         - Call sendLightCommand() to transmit control packet
         - Call sendLightControlCmd() to turn light on/off if needed
         - Return true
     - If "radio_err" or timeout: return false
- **Returns**: bool (true = valid sensor reply processed, false = no valid reply)

#### 22. `parseSensorPayload(const String& hexStr, SensorData& out)`
- **Purpose**: Decode 26-char hex string to 13-byte SensorData struct
- **Called**: By waitForSensorReply() and handleSlaveSerial()
- **Parameters**:
  - hexStr: 26 hex characters (13 bytes)
  - out: reference to SensorData struct (output)
- **Flow**:
  1. Validate hex string length (must be 26 chars)
  2. Call hexToBytes() to convert hex to binary
  3. Extract fields (big-endian):
     - Bytes 0-3: deviceId (uint32_t)
     - Bytes 4-5: temperature as int16_t, divide by 10 → float
     - Byte 6: humidity
     - Bytes 7-8: lux
     - Bytes 9-10: soilMoisture
     - Byte 11: waterLeak (non-zero = true)
     - Byte 12: battery
  4. Return true if success, false if parse error
- **Returns**: bool (true = valid payload, false = malformed)

#### 23. `publishSensorData(const SensorData& d, bool needsLight)`
- **Purpose**: Format sensor data as JSON and publish to MQTT
- **Called**: By waitForSensorReply() and handleSlaveSerial()
- **Parameters**:
  - d: SensorData struct with all readings
  - needsLight: boolean indicating if lux below threshold
- **Flow**:
  1. Build JSON object:
     ```json
     {
       "type": "sensorData",
       "deviceId": "0x01AABBCC",
       "temperature": 23.5,
       "humidity": 65,
       "lux": 150,
       "soilMoisture": 512,
       "waterLeak": false,
       "battery": 95,
       "needsLight": true
     }
     ```
  2. Print to Serial
  3. If MQTT connected, publish to TOPIC_STATUS
- **Returns**: void

#### 24. `calculateNextSleepSeconds()` ⏰
- **Purpose**: Compute next sleep interval for sensor node
- **Called**: By waitForSensorReply() before sending light command
- **Parameters**: None (uses global lastPingTime and millis())
- **Flow**:
  1. Calculate time to next ping: (lastPingTime + PING_INTERVAL_MS) - millis()
  2. Subtract BOOT_OVERHEAD_MS (3 sec for node to boot)
  3. Convert to seconds
  4. Clamp to MIN_SLEEP_S (10) and MAX_SLEEP_S (65000)
  5. Log calculated value to Serial
  6. Return as uint16_t
- **Returns**: uint16_t (sleep seconds)

---

### **Phase 7: Light Control Functions**

#### 25. `sendLightCommand(uint32_t targetDeviceId, uint16_t desiredLux, uint16_t nextSleepS)`
- **Purpose**: Send 8-byte control packet to sensor node with lux target and sleep interval
- **Called**: By waitForSensorReply() after receiving sensor data
- **Parameters**:
  - targetDeviceId: device ID of sensor node (e.g., 0x01AABBCC)
  - desiredLux: target lux level (0 if no light needed, 500 if needed)
  - nextSleepS: next sleep interval in seconds
- **Flow**:
  1. Check loraReady
  2. Build 8-byte packet (big-endian):
     - Bytes 0-3: targetDeviceId
     - Bytes 4-5: desiredLux
     - Bytes 6-7: nextSleepS
  3. XOR encrypt with SHARED_KEY
  4. Convert to 16-char hex string
  5. Send "radio tx [hex]"
  6. Wait for "radio_tx_ok"
  7. Log packet details to Serial
  8. Return true if TX successful, false if failed
- **Returns**: bool

#### 26. `sendLightControlCmd(bool turnOn)` 💡
- **Purpose**: Send ON/OFF command to light node (device 0x00000005)
- **Called**: By mqttCallback (MQTT control) or handleSerialLightControlInput (manual test)
- **Parameters**: turnOn (true = ON, false = OFF)
- **Flow**:
  1. Check loraReady
  2. Retry up to maxRetries (currently 1)
  3. Build packet with light node device ID (0x00000005) and command (0x01 for ON, 0x00 for OFF)
  4. Send "radio tx [hex]"
  5. Call waitForLightAck(turnOn) to verify ACK received
  6. If ACK OK, call publishLightControlState()
  7. If failed, retry
  8. Return true if at least one retry succeeded
- **Returns**: bool

#### 27. `waitForLightAck(bool turnOn)` 🔄
- **Purpose**: Wait for light node to acknowledge command
- **Called**: By sendLightControlCmd()
- **Parameters**: turnOn (whether this was ON or OFF command)
- **Flow**:
  1. Enter RX mode ("radio rx 0")
  2. Wait ACK_TIMEOUT_MS (5 sec) for "radio_rx [hex]" response
  3. Decode response:
     - If device ID matches light node (0x00000005)
     - If status byte is 0x01: ACK OK (return 1)
     - If status byte is 0x00: ACK FAIL (return 0)
  4. If timeout or error: return -1
- **Returns**: int (1 = OK, 0 = FAIL, -1 = TIMEOUT)

---

### **Phase 8: Utility Functions**

#### 28. `makeDevicePacket(uint32_t deviceId, uint8_t value)`
- **Purpose**: Create 5-byte device ID + value packet, XOR encrypt, return as hex string
- **Called**: By sendLightControlCmd()
- **Parameters**:
  - deviceId: target device (e.g., 0x00000005 for light node)
  - value: command byte (0x00 = OFF, 0x01 = ON)
- **Flow**:
  1. Build 5-byte buffer: [ID high, ID mid-high, ID mid-low, ID low, value]
  2. XOR encrypt with SHARED_KEY
  3. Convert to 10-char hex string
  4. Return
- **Returns**: String (10-char hex)

#### 29. `hexToBytes(const String& hexStr, uint8_t* out, size_t outLen)`
- **Purpose**: Convert hex string to byte array
- **Called**: By parseSensorPayload(), waitForSensorReply()
- **Parameters**:
  - hexStr: hex string (e.g., "A50149474F50")
  - out: output byte array
  - outLen: size of output array
- **Flow**:
  1. Validate hexStr.length() == outLen * 2
  2. For each pair of hex chars:
     - Call hexNibble() to convert each char to 0-15
     - Combine: byte = (high nibble << 4) | low nibble
  3. Return true if success, false if format error
- **Returns**: bool

#### 30. `bytesToHex(const uint8_t* data, size_t len)`
- **Purpose**: Convert byte array to hex string
- **Called**: By sendPing(), sendLightCommand(), makeDevicePacket()
- **Parameters**:
  - data: input byte array
  - len: number of bytes
- **Flow**:
  1. For each byte:
     - Convert high nibble (0-15) to hex char ('0'-'9', 'A'-'F')
     - Convert low nibble to hex char
     - Append both to output String
  2. Return uppercase hex string
- **Returns**: String (hex representation)

#### 31. `hexNibble(char c)`
- **Purpose**: Convert single hex character ('0'-'9', 'a'-'f', 'A'-'F') to value (0-15)
- **Called**: By hexToBytes()
- **Parameters**: c (single hex character)
- **Flow**:
  1. If c >= '0' && c <= '9': return c - '0'
  2. If c >= 'a' && c <= 'f': return c - 'a' + 10
  3. If c >= 'A' && c <= 'F': return c - 'A' + 10
  4. Else: return -1 (error)
- **Returns**: int (0-15, or -1 for invalid)

#### 32. `xorWithKey(uint8_t* data, size_t len)`
- **Purpose**: XOR encrypt/decrypt data with SHARED_KEY (cycles through 4-byte key)
- **Called**: By sendPing(), waitForSensorReply(), sendLightCommand(), makeDevicePacket()
- **Parameters**:
  - data: byte array to encrypt/decrypt (modified in place)
  - len: length of data
- **Flow**:
  1. For each byte at index i:
     - data[i] ^= SHARED_KEY[i % 4]
  2. (XOR is reversible: apply twice to get original)
- **Returns**: void (modifies data in place)

#### 33. `isApprovedDevice(uint32_t id)` 🔐
- **Purpose**: Check if device ID is in whitelist of approved sensor nodes
- **Called**: By waitForSensorReply() to validate received device ID
- **Parameters**: id (device ID to check)
- **Flow**:
  1. Loop through APPROVED_DEVICE_IDS array
  2. If id matches any entry, return true
  3. If no match found, return false
- **Returns**: bool (true = approved, false = rogue/unknown node)

---

## Communication Protocols

### UART1: RN2483 LoRa Module (57600 baud)

#### AT Command Format
```
Request (Gateway → RN2483):
  <command>\r\n
  Example: "radio tx A50149474F50\r\n"

Response (RN2483 → Gateway):
  <response>\r\n
  Examples:
    "ok\r\n"
    "radio_tx_ok\r\n"
    "radio_rx A501494D4F50\r\n"
    "radio_err\r\n"
    "invalid_param\r\n"
```

#### Common Commands
```
Initialization:
  sys get ver              → Returns RN2483 firmware version
  mac pause                → Disable LoRaWAN MAC, enable raw LoRa P2P
  
Radio Configuration:
  radio set freq 868100000 → Set frequency
  radio set sf sf12        → Set spreading factor
  radio set pwr 14         → Set TX power
  radio set crc on         → Enable CRC
  
Transmission:
  radio tx <hex_payload>   → Transmit packet (hex string)
  Response: "ok" (accepted), then "radio_tx_ok" (completed)
  
Reception:
  radio rx 0               → Listen until packet or watchdog
  Response: "radio_rx <hex_payload>" (packet received)
           or "radio_err" (timeout/error)
  
  radio rxstop             → Stop RX mode
  Response: "ok"
```

### UART2: Gateway-Slave Bridge (115200 baud)

#### Command Protocol
```
Main Gateway → Slave:
  <command>\n
  Examples:
    "FREQ:120\n"     - Set LoRaWAN TX frequency
    "SLEEP:3600\n"   - Set sleep duration

Slave → Main Gateway:
  <hex_payload>\n   - Forward received sensor data
  "ACK\n"           - Command acknowledged
  "ERR\n"           - Error
```

### MQTT Protocol

#### Topics

**Subscriptions (gateway receives)**:
- `esp32/myroom123/ping`: Send "PING" to trigger manual wake-up sequence
- `esp32/myroom123/control`: Send "ON"/"OFF" or "LIGHT_ON"/"LIGHT_OFF" to control LED

**Publications (gateway sends)**:
- `esp32/myroom123/status`: All outgoing messages (heartbeat, sensor data, status)

#### Message Formats

**Heartbeat**:
```
Hello from ESP32 | uptime(s): 12345 | LED: ON
```

**Sensor Data**:
```json
{
  "type": "sensorData",
  "deviceId": "0x01AABBCC",
  "temperature": 23.5,
  "humidity": 65,
  "lux": 150,
  "soilMoisture": 512,
  "waterLeak": false,
  "battery": 95,
  "needsLight": true
}
```

**Light Control State**:
```json
{
  "type": "LED",
  "deviceId": "0x00000005",
  "state": "ON"
}
```

**Status Messages**:
```
Manual LoRa PING received a sensor reply
Manual LoRa PING retry window expired
RN2483 init failed
WiFi connected, IP: 192.168.1.100
```

---

## Security & Obfuscation

### XOR Encryption Mechanism

#### Purpose
- **Not cryptographically strong**, but effective for:
  - Filtering out random RF noise
  - Rejecting packets from rogue/unauthorized nodes
  - Simple obfuscation for casual eavesdropping

#### Implementation
```cpp
static const uint8_t SHARED_KEY[4] = { 0xA3, 0x7F, 0x2C, 0x91 };

void xorWithKey(uint8_t* data, size_t len) {
  for (size_t i = 0; i < len; i++) {
    data[i] ^= SHARED_KEY[i % 4];  // Cycles: key[0], key[1], key[2], key[3], key[0]...
  }
}
```

#### Encryption/Decryption Process

**Transmit (Sensor Node)**:
1. Build 13-byte SensorData struct
2. Call xorWithKey(data, 13)
3. Convert 13 bytes to 26-char hex string
4. Transmit via LoRa radio

**Receive (Gateway)**:
1. Receive 26-char hex string from radio
2. Convert to 13 bytes
3. Call xorWithKey(data, 13) [XOR is reversible]
4. Parse decrypted bytes into SensorData struct

#### PING/ACK Encryption

**Gateway Sends PING**:
1. Build 8-byte packet: 0x50494E47 (ASCII "PING") + 0xA37F2C91 (SHARED_KEY)
2. Call xorWithKey(pingBuf, 8)
3. Transmit 16-char hex string

**Sensor Receives PING**:
1. Receive 16-char hex string
2. Convert to 8 bytes
3. Call xorWithKey(data, 8)
4. Check if bytes 0-3 == "PING" and bytes 4-7 == SHARED_KEY
5. If match, accept as valid wake-up signal

#### Reversibility Property
```
Original:        [0x50, 0x49, 0x4E, 0x47, ...]
After XOR once:  [0xF3, 0x76, 0x72, 0xD4, ...]
After XOR again: [0x50, 0x49, 0x4E, 0x47, ...]  ← Back to original
```

### Whitelist Validation

#### Approved Device Array
```cpp
static const uint32_t APPROVED_DEVICE_IDS[] = {
  0x01AABBCC   // sensor node 1
};
```

#### Validation Flow
1. Gateway receives encrypted SensorData packet
2. Decrypt with XOR
3. Extract deviceId (first 4 bytes)
4. Check if deviceId exists in APPROVED_DEVICE_IDS
5. If yes: process and publish to MQTT
6. If no: reject with "Rejected: unknown device 0xXXXXXXXX"

#### Security Implications
- **Prevents rogue nodes** from sending fake sensor data to dashboard
- **Prevents interference** from other LoRa devices in the area
- **Simple whitelist** is maintainable without centralized PKI
- **But not cryptographically secure**: anyone with SHARED_KEY can forge packets

---

## Summary of Data Flow

### Typical 2-Minute Cycle

```
T=0s:     [Scheduled PING Sent]
          ├─ sendPing("scheduled")
          ├─ Transmit 8-byte PING via LoRa
          └─ Wait for radio_tx_ok

T=0.5s:   [Node Wakes Up]
          ├─ Sensor node RN2483 receives PING broadcast
          ├─ Node MCU wakes from sleep
          └─ Node collects sensor data (DHT22, TSL2561, capacitive sensor, etc.)

T=0.5-1s: [Listening Window Opens]
          ├─ Gateway enters RX mode
          ├─ sendCommand("radio rx 0")
          └─ Listen timeout: 10 seconds

T=1-2s:   [Node Sends Reply]
          ├─ Sensor node builds 13-byte SensorData struct
          ├─ XOR encrypt with SHARED_KEY
          ├─ Convert to 26-char hex string
          └─ Transmit via LoRa radio

T=1.5s:   [Gateway Receives Data]
          ├─ "radio_rx 50494E4749FF1FA2B2..."
          ├─ Extract hex payload
          ├─ XOR decrypt
          ├─ parseSensorPayload() → SensorData struct
          ├─ Validate device ID (whitelist check)
          ├─ Calculate if light needed (lux < 200?)
          ├─ publishSensorData() to MQTT
          └─ JSON published to "esp32/myroom123/status"

T=1.9s:   [Light Control]
          ├─ If lux < 200:
          │  ├─ calculateNextSleepSeconds()
          │  ├─ sendLightCommand(deviceId, 500, nextSleepS)
          │  └─ sendLightControlCmd(true) → turn light ON
          └─ If lux >= 200:
             ├─ sendLightCommand(deviceId, 0, nextSleepS) → sync-only
             └─ Do NOT turn light on

T=2s:     [Node Returns to Sleep]
          ├─ Sensor node receives light/sync command (if still listening)
          ├─ Updates next sleep interval from command payload
          └─ Enters deep sleep

T=120s:   [Cycle Repeats]
          ├─ Heartbeat published at T=60s, 120s, 180s, etc.
          ├─ Next PING sent at T=120s
          └─ Loop continues
```

---

## Testing & Debugging

### Serial Monitor Output

```
=== Greenhouse Gateway starting ===
Connecting to WiFi: WIFI
WiFi connected, IP: 192.168.1.50

RN2483 banner: RN2483 1.0.5 Dec 19 2017
RN2483 version: RN2483 1.0.5 Dec 19 2017
RN2483 <= mac pause
RN2483 => 200,862,000
RN2483 <= radio set mod lora
RN2483 => ok
... [13 more radio config commands] ...
Gateway ready.

MQTT connect to broker.emqx.io:1883
MQTT connected

[Every 120 seconds]
Sending PING (scheduled)
RN2483 <= radio tx 50494E47A37F2C91
RN2483 => ok
RN2483 => radio_tx_ok
Listening for sensor reply (10000 ms)...
RN2483 <= radio rx 0
RN2483 => ok
RN2483 => radio_rx A5014947503030D2
RX payload hex: A5014947503030D2...
Sensor: {"type":"sensorData","deviceId":"0x01AABBCC","temperature":23.5,"humidity":65,"lux":150,...}

[Every 60 seconds]
Heartbeat: Hello from ESP32 | uptime(s): 3600 | LED: ON
```

### Manual Testing via MQTT

```bash
# Terminal 1: Subscribe to status updates
mosquitto_sub -h broker.emqx.io -t "esp32/myroom123/status"

# Terminal 2: Trigger manual PING
mosquitto_pub -h broker.emqx.io -t "esp32/myroom123/ping" -m "PING"

# Expected output (Terminal 1):
# {"type":"sensorData","deviceId":"0x01AABBCC",...}

# Terminal 3: Control light
mosquitto_pub -h broker.emqx.io -t "esp32/myroom123/control" -m "ON"
mosquitto_pub -h broker.emqx.io -t "esp32/myroom123/control" -m "OFF"
```

---

## Configuration & Tuning

### Key Timing Parameters
```cpp
PING_INTERVAL_MS         = 120,000  (2 min)  - Lower = more responsive, higher power
POST_PING_WAIT_MS        = 10,000   (10 sec) - RX listen window
HEARTBEAT_INTERVAL_MS    = 60,000   (1 min)  - MQTT keep-alive
MQTT_RECONNECT_INTERVAL  = 3,000    (3 sec)  - Retry connection if dropped
BOOT_OVERHEAD_MS         = 3,000    (3 sec)  - Node wake-up time buffer
```

### Adjusting for Your Environment
- **Increase PING_INTERVAL_MS** (e.g., 180,000): Less frequent pings save sensor battery but slower response time
- **Decrease PING_INTERVAL_MS** (e.g., 60,000): More responsive but uses more sensor power
- **Increase POST_PING_WAIT_MS** (e.g., 15,000): Better for weak RF conditions but uses more gateway power

---

## Conclusion

The **Gateway** implements a complete IoT system bridging LoRa sensor nodes, WiFi connectivity, and cloud MQTT infrastructure. Its hierarchical execution flow (initialization → main loop → event-driven callbacks) ensures reliable 24/7 operation while managing multiple communication protocols (UART, LoRa AT commands, MQTT, WiFi) simultaneously.

Key design principles:
- **Always-on architecture**: Gateway never sleeps; external power required
- **Distributed sleep**: Sensor nodes sleep between pings to conserve battery
- **Secure whitelist**: Only approved devices can publish sensor data
- **Automatic light control**: Lux-based decision-making for supplemental grow lights
- **Extensible slave bridge**: Secondary LoRaWAN board adds cloud uplink capability without main code changes

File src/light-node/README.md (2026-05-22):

# ESP32 Light Node - Smart Grow Light Controller

## Table of Contents
1. [System Overview](#system-overview)
2. [Hardware Architecture](#hardware-architecture)
3. [Integration with Gateway](#integration-with-gateway)
4. [Data Structures](#data-structures)
5. [Execution Flow](#execution-flow)
6. [Methods Reference](#methods-reference)
7. [Communication Protocol](#communication-protocol)
8. [Setup & Deployment](#setup--deployment)

---

## System Overview

### Purpose
The **Light Node** is a specialized ESP32 device that receives ON/OFF commands from the main gateway and controls supplemental grow lights via GPIO relay or direct LED output. It listens continuously on the same LoRa frequency as the sensor network and executes light commands in real-time.

### Key Responsibilities
- **Command Reception**: Continuously listen for gateway light ON/OFF commands on 868.1 MHz
- **LED Control**: Switch GPIO pin HIGH/LOW to drive relay or LED
- **Acknowledgment**: Transmit ACK packet back to gateway confirming command success/failure
- **Always-On**: No sleep; powered externally via USB or AC adapter
- **Fixed Device ID**: Hardcoded as 0x00000005 (light node identifier)

### When to Use
- **Automatic light control**: Gateway sends ON command when lux drops below threshold
- **Real-time response**: Grow lights activate immediately based on ambient conditions
- **Feedback loop**: ACK packet confirms light state change to dashboard
- **Scalable**: Can expand to multiple light nodes (different device IDs) if needed

---

## Hardware Architecture

### Main Components

#### **ESP32 Microcontroller (Light Node)**
- **Role**: Light control relay driver
- **Power**: USB or AC adapter (always-on, no battery)
- **UART Ports**:
  - **UART1** (pins 18/19): Connected to RN2483 LoRa module at 57600 baud
  - **UART0** (USB): USB Serial for debugging at 115200 baud
- **GPIO Output**:
  - **GPIO2**: LED control or relay driver (active-HIGH)
- **Device ID**: 0x00000005 (hard-coded, all light nodes share this or use variants like 0x00000005, 0x00000006, etc.)

#### **RN2483 LoRa Module (P2P)**
- **Communication**: Connected via UART1 at 57600 baud
- **Protocol**: LoRa P2P (same as sensor nodes, proprietary mode)
- **Frequency**: 868.1 MHz (European ISM band)
- **Purpose**: Receive ON/OFF commands from gateway, send ACK back
- **Interface**: AT command protocol

### Pin Mapping

```
ESP32 (Light Node) Pin Configuration:
├─ UART1 (LoRa P2P):
│  ├─ GPIO18 (RX) <- RN2483 TX
│  └─ GPIO19 (TX) -> RN2483 RX
├─ GPIO23: RN2483 Reset (active-low)
├─ GPIO2: LED/Relay Output (active-HIGH)
│  └─ Drive relay coil or direct LED control
│      HIGH = Light ON
│      LOW = Light OFF
└─ UART0 (USB Serial @ 115200):
   └─ Used for Serial.print() debugging

Baud Rates:
├─ UART1: 57600 (RN2483 standard)
└─ USB Serial: 115200 (debugging)
```

### Relay Wiring (if controlling external load)

```
GPIO2 (ESP32)
    ↓
    [220Ω resistor]
    ↓
    [NPN transistor base]
    |
    [Relay coil]  ← GND
    
NC (normally closed) contact
    ↓
    [Grow light power supply 120V AC]
    ↓
    [Grow light fixture]
```

---

## Integration with Gateway

### Command Reception Flow

```
T=0s    Gateway detects low lux (< 200 lux)
        └─ calculateNextSleepSeconds()
           └─ sendLightControlCmd(true)

T=0-100ms  Gateway RN2483 TX:
           ├─ Build 5-byte packet: [0x00,0x00,0x00,0x05][0x01 = ON]
           ├─ XOR encrypt with SHARED_KEY
           ├─ Convert to hex: "0000000501ABCDEF" (10 chars + check)
           └─ Transmit: "radio tx 0000000501ABCDEF..."

T=0.5s  Light Node RN2483 receives broadcast
        └─ RN2483 radio interrupt (in RX mode)

T=0.5s-1s  Light Node MCU wakes on RX event:
           ├─ "radio_rx 0000000501XXXXXX"
           ├─ Decrypt (XOR): [0x00,0x00,0x00,0x05][0x01]
           ├─ Check device ID: matches 0x00000005 ✓
           ├─ Check command: 0x01 = ON ✓
           ├─ digitalWrite(GPIO2, HIGH) → Light ON
           ├─ Print "Light ON" to Serial
           └─ Store cmd_state = true

T=1-2s  Light Node builds ACK packet:
        ├─ 5-byte ACK: [0x00,0x00,0x00,0x05][0x01 = success]
        ├─ XOR encrypt
        ├─ Convert to hex
        └─ Transmit: "radio tx ..."

T=2-3s  Gateway (still in RX mode) receives ACK:
        └─ publishLightControlState() → MQTT
           └─ {"type":"LED","state":"ON"}
```

### Graceful Degradation

```
Scenario 1: ACK Received Successfully
  Gateway receives ACK with status=0x01
  └─ publishLightControlState() with state="ON"
  └─ Dashboard shows light successfully turned ON

Scenario 2: ACK Lost (timeout after ACK_TIMEOUT_MS = 5s)
  Gateway does NOT receive ACK
  └─ Retries once (maxRetries = 1)
  └─ If still no ACK: publishStatus("Light command may have failed")
  └─ Dashboard shows unknown state
  └─ Light may be ON (command succeeded but ACK lost)
  └─ Light may be OFF (command failed)
  
  Note: This is acceptable; user can manually verify LED status

Scenario 3: Command Never Received
  Light Node not powered or out of range
  └─ Gateway: ACK timeout → retry
  └─ After retries: "Light command failed"
```

---

## Data Structures

### Light Control Command (5 bytes, from gateway)

**Sent by gateway, received by light node**:
```
uint8_t lightCmd[5] = {
  0x00,           // Byte 0: Device ID high byte
  0x00,           // Byte 1: Device ID mid-high byte
  0x00,           // Byte 2: Device ID mid-low byte
  0x05,           // Byte 3: Device ID low byte (0x00000005)
  0x01            // Byte 4: Command (0x01 = ON, 0x00 = OFF)
};

Total: 4-byte device ID + 1-byte command = 5 bytes
Transmitted as 10-character hex string: "0000000501"

Encryption: XOR with SHARED_KEY (cycles through 4 bytes)
Before XOR: [0x00, 0x00, 0x00, 0x05, 0x01]
After XOR:  [0x00^0xA3, 0x00^0x7F, 0x00^0x2C, 0x05^0x91, 0x01^0xA3]
           = [0xA3, 0x7F, 0x2C, 0x94, 0xA2]
Hex: "A37F2C94A2"
```

### Light ACK Packet (5 bytes, from light node)

**Response sent by light node to gateway**:
```
uint8_t ack[5] = {
  0x00,           // Byte 0: Device ID high byte
  0x00,           // Byte 1: Device ID mid-high byte
  0x00,           // Byte 2: Device ID mid-low byte
  0x05,           // Byte 3: Device ID low byte (0x00000005)
  0x01            // Byte 4: Status (0x01 = success, 0x00 = failure)
};

Encryption: Same XOR process as command
```

### Command Values

```cpp
#define CMD_LIGHT_ON   0x01
#define CMD_LIGHT_OFF  0x00
#define ACK_OK         0x01
#define ACK_FAIL       0x00

Examples:
  "0000000501" → Turn light ON, expect ACK with 0x01
  "0000000500" → Turn light OFF, expect ACK with 0x00
  "0000000501" with status=0x00 → Command failed (light not responding)
```

---

## Execution Flow

### Boot Sequence

```
main() [Arduino startup]
  ↓
setup()
  ├─ Initialize Serial (115200 USB debug)
  ├─ Initialize GPIO (LED/relay pin, reset pin)
  │  └─ Set GPIO2 to OUTPUT, initial state LOW (light OFF)
  │
  ├─ connectToLoRa()
  │  ├─ Reset RN2483 (GPIO23 pulse)
  │  ├─ Begin UART1 @ 57600 baud
  │  ├─ Get version, pause MAC, configure radio (13 commands)
  │  └─ Set loraReady = true
  │
  └─ Print "Light node ready"
     └─ Initial state: LED OFF, listening for commands

[Loop begins]
```

### Main Loop (continuous listening)

```
loop() [runs continuously]
  ├─ Ensure LoRa RX active:
  │  └─ If not in RX mode: "radio rx 0"
  │
  ├─ Check for incoming command:
  │  └─ readLoRaLine(timeout = 100ms)
  │     ├─ If "radio_rx <hex>" received:
  │     │  ├─ Extract 5-byte payload
  │     │  ├─ Decrypt (XOR)
  │     │  ├─ Check device ID (must be 0x00000005)
  │     │  ├─ Extract command (0x01 = ON, 0x00 = OFF)
  │     │  │
  │     │  ├─ If device ID matches:
  │     │  │  ├─ If command == 0x01:
  │     │  │  │  ├─ digitalWrite(GPIO2, HIGH) → Light ON
  │     │  │  │  ├─ ledState = true
  │     │  │  │  └─ ack_status = 0x01 (success)
  │     │  │  ├─ Else if command == 0x00:
  │     │  │  │  ├─ digitalWrite(GPIO2, LOW) → Light OFF
  │     │  │  │  ├─ ledState = false
  │     │  │  │  └─ ack_status = 0x01 (success)
  │     │  │  └─ Call transmitAck(ack_status)
  │     │  │
  │     │  └─ If device ID does NOT match:
  │     │     └─ Ignore (not for this light node)
  │     │
  │     └─ If "radio_err" or no packet:
  │        └─ Continue listening (non-blocking)
  │
  └─ Repeat loop
```

---

## Methods Reference

### **Phase 1: Initialization**

#### 1. `connectToLoRa()`
- **Purpose**: Initialize RN2483 LoRa P2P module
- **Called**: Once during setup
- **Parameters**: None
- **Flow**:
  1. Reset RN2483 (GPIO23 pulse)
  2. Begin UART1 @ 57600
  3. Flush serial
  4. Get version
  5. Send "mac pause" (P2P mode)
  6. Configure 13 radio parameters (frequency, SF, BW, CRC, etc.)
  7. Enter continuous RX: "radio rx 0"
- **Returns**: bool (true if all commands succeed)

---

### **Phase 2: Main Loop**

#### 2. `checkForCommand()` 🎯 **CRITICAL**
- **Purpose**: Check if light command received and process it
- **Called**: Every loop iteration
- **Parameters**: None
- **Flow**:
  1. Call readLoRaLine(100ms timeout)
  2. If "radio_rx <hex>" received:
     - Extract 10-char hex string (5 bytes)
     - hexToBytes() → convert to 5-byte buffer
     - xorWithKey() → decrypt
     - Parse: deviceId (bytes 0-3), command (byte 4)
     - If deviceId == 0x00000005:
       - If command == 0x01:
         - digitalWrite(GPIO2, HIGH)
         - setLed(true)
         - transmitAck(0x01)
       - Else if command == 0x00:
         - digitalWrite(GPIO2, LOW)
         - setLed(false)
         - transmitAck(0x01)
     - Else: ignore (not for this node)
  3. Continue listening
- **Returns**: void

#### 3. `transmitAck(uint8_t status)` 📤
- **Purpose**: Send ACK packet back to gateway
- **Called**: After processing valid command
- **Parameters**: status (0x01 = success, 0x00 = failure)
- **Flow**:
  1. Build 5-byte ACK buffer:
     - Bytes 0-3: 0x00000005 (device ID, big-endian)
     - Byte 4: status (0x01 or 0x00)
  2. xorWithKey() → encrypt
  3. bytesToHex() → convert to 10-char hex
  4. sendLoRaCommand("radio tx <hex>")
  5. Wait for "radio_tx_ok"
  6. Log to Serial
- **Returns**: bool (true = ACK sent, false = TX failed)

---

### **Phase 3: LoRa Communication**

#### 4. `readLoRaLine(int timeoutMs)`
- **Purpose**: Read one line from RN2483 with timeout
- **Called**: By checkForCommand()
- **Parameters**: timeoutMs (timeout in milliseconds)
- **Flow**:
  1. Initialize timer, empty String
  2. While elapsed < timeout:
     - If available: read char
     - Skip '\r'
     - If '\n': return trimmed line
     - Else: append char
  3. Return accumulated (may be empty)
- **Returns**: String

#### 5. `sendLoRaCommand(const String& cmd, int timeoutMs)`
- **Purpose**: Send AT command to RN2483
- **Called**: During initialization and ACK TX
- **Parameters**:
  - cmd: AT command (e.g., "radio rx 0")
  - timeoutMs: response timeout
- **Flow**:
  1. Print to loraSerial with "\r\n"
  2. readLoRaLine(timeoutMs)
  3. Return response
- **Returns**: String

#### 6. `flushLoRaInput()`
- **Purpose**: Clear serial buffer
- **Called**: Before RX mode
- **Parameters**: None
- **Flow**:
  1. While available: read and discard
- **Returns**: void

---

### **Phase 4: Utility Functions**

#### 7. `setLed(bool on)`
- **Purpose**: Turn physical LED on/off (GPIO2)
- **Called**: After command execution
- **Parameters**: on (true = ON, false = OFF)
- **Flow**:
  1. digitalWrite(GPIO2, on ? HIGH : LOW)
  2. Log to Serial
- **Returns**: void

#### 8. `bytesToHex(const uint8_t* data, size_t len)`
- **Purpose**: Convert byte array to hex string
- **Called**: By transmitAck()
- **Parameters**:
  - data: input bytes
  - len: length
- **Flow**:
  1. For each byte: extract high/low nibble, convert to hex char
  2. Return uppercase hex string
- **Returns**: String

#### 9. `hexToBytes(const String& hexStr, uint8_t* out, size_t outLen)`
- **Purpose**: Convert hex string to bytes
- **Called**: By checkForCommand()
- **Parameters**:
  - hexStr: hex input
  - out: output buffer
  - outLen: output length
- **Flow**:
  1. Validate length (must be 2*outLen)
  2. For each pair: convert hex chars to nibbles, combine
  3. Return true if success
- **Returns**: bool

#### 10. `xorWithKey(uint8_t* data, size_t len)`
- **Purpose**: XOR encrypt/decrypt with SHARED_KEY
- **Called**: By checkForCommand() and transmitAck()
- **Parameters**:
  - data: buffer to encrypt/decrypt (modified in place)
  - len: length
- **Flow**:
  1. For each byte i: data[i] ^= SHARED_KEY[i % 4]
- **Returns**: void

---

## Communication Protocol

### UART1: RN2483 LoRa P2P (57600 baud)

```
Request: <command>\r\n
Response: <response>\r\n

Examples:
  IN:  "radio rx 0\r\n"
  OUT: "ok\r\n"
  
  OUT: "radio_rx 0000000501XXXXXX\r\n"  [command received]
  
  IN:  "radio tx 0000000501YYYYYY\r\n"
  OUT: "ok\r\n"
  OUT: "radio_tx_ok\r\n"  [ACK sent]
```

---

## Setup & Deployment

### Configuration

**File**: [light-node/light-node.ino](light-node.ino) (lines 30-40)

```cpp
const uint32_t lightNodeId = 5UL;  // 0x00000005 (or 6, 7, etc. for multiple nodes)
const uint8_t cmdOff = 0x00;
const uint8_t cmdOn  = 0x01;
const uint8_t ackFail = 0x00;
const uint8_t ackOk   = 0x01;

#define LORA_FREQ        868100000UL  // Must match gateway
#define LORA_SF          "sf12"       // Must match gateway
#define LORA_PWR         14           // Must match gateway

#define LED_PIN 2  // GPIO2 - relay/light control
```

**Important**: Light node device ID (0x00000005) must be recognized by gateway (or set `sendLightControlCmd()` to use this ID).

### Flashing Procedure

```
Board: ESP32 Dev Module
Upload Speed: 921600
Port: COM[your device]
File: light-node/light-node.ino
```

### Verification

**Serial Monitor Output** (115200 baud):
```
Light node starting...
RN2483 connected.
Radio configured (SF12, 868.1 MHz, P2P mode).
Entering RX mode...
Light node ready.

[Waiting for commands...]

[If command received]
radio_rx 0000000501XXXXXX
Decrypted: [0x00, 0x00, 0x00, 0x05, 0x01]
Device ID: 0x00000005 ✓
Command: ON (0x01)
Light ON
Sending ACK...
radio_tx 0000000501YYYYYY
radio_tx_ok
ACK sent.

[Back to listening...]
```

---

## Multi-Light Setup

To control multiple lights:

1. **Create variants with different device IDs**:
   ```cpp
   // light-node-1.ino
   const uint32_t lightNodeId = 5UL;  // 0x00000005
   
   // light-node-2.ino
   const uint32_t lightNodeId = 6UL;  // 0x00000006
   
   // light-node-3.ino
   const uint32_t lightNodeId = 7UL;  // 0x00000007
   ```

2. **Update gateway to send individual commands**:
   ```cpp
   // In gateway.cpp mqttCallback()
   if (msg.equalsIgnoreCase("LIGHT1 ON"))
     sendLightControlCmd(true, 0x00000005);
   else if (msg.equalsIgnoreCase("LIGHT2 ON"))
     sendLightControlCmd(true, 0x00000006);
   ```

3. **Flash each light node with its variant**
4. **Each light node responds only to its device ID**

---

## Summary

The **Light Node** provides real-time grow light control by:

| Aspect | Detail |
|---|---|
| **Device ID** | 0x00000005 (or configurable variants) |
| **Power** | External (USB/AC), always-on |
| **Control Mode** | LoRa P2P, continuous RX listening |
| **Response Time** | <1 second from command TX to light activation |
| **Output** | GPIO2 (can drive relay or direct LED) |
| **Feedback** | ACK packet to confirm state change |
| **Range** | ~1-2 km P2P with SF12 |

**Key Functions**:
1. Initialize RN2483 in RX mode
2. Wait for valid 5-byte light command
3. Decrypt and validate device ID
4. Activate/deactivate GPIO2 (light ON/OFF)
5. Send ACK packet to confirm

See [Main Gateway Documentation](../gateway/README.md) for system-wide architecture.

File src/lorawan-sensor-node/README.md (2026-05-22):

# ESP32 LoRaWAN Sensor Node - Cloud-Direct Environmental Monitor

## Table of Contents
1. [System Overview](#system-overview)
2. [Hardware Architecture](#hardware-architecture)
3. [Integration with Cloud](#integration-with-cloud)
4. [Data Structures](#data-structures)
5. [Execution Flow](#execution-flow)
6. [Methods Reference](#methods-reference)
7. [Communication Protocols](#communication-protocols)
8. [Setup & Deployment](#setup--deployment)

---

## System Overview

### Purpose
The **LoRaWAN Sensor Node** is an alternative to the P2P sensor node that connects directly to the cloud (Loriot, TTN, or other LoRaWAN network server) instead of relying on the main gateway. It uploads sensor data periodically and can receive commands via Class A downlinks.

### Key Responsibilities
- **LoRaWAN Join**: Perform OTAA join to Loriot EU868 cluster once at startup
- **Periodic Uplinks**: Send 13-byte sensor payload every TX_INTERVAL_MS (30-3600 seconds)
- **Downlink Reception**: Receive frequency/sleep updates via Class A downlinks
- **Sleep Management**: Deep sleep between transmissions (configurable interval)
- **Independent Operation**: Works without main gateway (different network topology)

### When to Use
- **Dedicated cloud pathway**: When P2P coverage is poor but LoRaWAN coverage is good
- **Cloud-first monitoring**: Direct data logging in LoRaWAN network backend
- **Multi-network redundancy**: Sensor data goes to cloud AND P2P gateway (if both devices present)
- **Standalone deployment**: Single sensor node in area without main gateway
- **Device ID**: 0x02AABBCC (MSB 0x02 identifies as LoRaWAN node type)

---

## Hardware Architecture

### Main Components

#### **ESP32 Microcontroller (LoRaWAN Sensor)**
- **Role**: LoRaWAN endpoint with sensors
- **Power**: Battery (2×AA) or USB, with periodic deep sleep
- **UART Ports**:
  - **UART1** (pins 18/19): Connected to RN2483 LoRaWAN module at 57600 baud
  - **UART0** (USB): USB Serial for debugging at 115200 baud (programming only)
- **Sensors**: Same as P2P sensor node (DHT22, light, soil moisture, water leak, battery)
- **Sleep**: RTC timer for wake-up on interval
- **Device ID**: 0x02AABBCC (MSB 0x02 = LoRaWAN node type)

#### **RN2483 LoRa Module (LoRaWAN)**
- **Communication**: Connected via UART1 at 57600 baud
- **Protocol**: LoRaWAN Class A (OTAA join)
- **Frequency**: 868.1 MHz (EU868 cluster)
- **Network**: Loriot backend (iotnet.teracom.dk)
- **Purpose**: Send sensor data to cloud, receive downlinks
- **Interface**: AT command protocol (via rn2xx3 library)

### Pin Mapping

```
ESP32 (LoRaWAN Sensor Node) Pin Configuration:
├─ UART1 (LoRaWAN):
│  ├─ GPIO18 (RX) <- RN2483 TX
│  └─ GPIO19 (TX) -> RN2483 RX
├─ GPIO23: RN2483 Reset (active-low)
├─ GPIO2: LED (activity indicator)
├─ Analog Sensors (same as P2P node):
│  ├─ GPIO34: Light sensor
│  ├─ GPIO35: Soil moisture
│  └─ GPIO33: Water leak
├─ GPIO4: DHT22 data line
└─ UART0 (USB Serial @ 115200):
   └─ Debugging during development only

Baud Rates:
├─ UART1: 57600 (RN2483 standard)
└─ USB Serial: 115200 (debugging)
```

---

## Integration with Cloud

### Data Flow Architecture

```
                    ☁️ Loriot Cloud
                    (EU868 cluster)
                         ↑
                    LoRaWAN uplink
                    (port 1 or 2)
                         |
    ┌────────────────────┴────────────────┐
    │   RN2483 LoRaWAN Module            │
    │   (EU868, Class A)                 │
    └────────────────────┬────────────────┘
                         ↑
                    UART1 @ 57600
                         |
    ┌─────────────────────────────────────┐
    │  ESP32 LoRaWAN Sensor Node          │
    │  ├─ DHT22 (temp/humidity)           │
    │  ├─ Light sensor (lux)              │
    │  ├─ Soil moisture (ADC)             │
    │  ├─ Water leak detector             │
    │  └─ Battery ADC                     │
    └─────────────────────────────────────┘
         ↓
    Deep sleep (60-3600 seconds)
         ↓
    [RTC timer wakes CPU]
         ↓
    Repeat cycle
```

### LoRaWAN Class A Receive Window

```
T=0s    Device sends uplink to Loriot on port 2
        └─ "mac tx ucnf 2 <13-byte payload>"

T=0-5s  RN2483 waits for confirmation
        └─ "mac_tx_ok" (uplink confirmed sent)

T=5-6s  Device listens on RX1 window
        └─ Loriot can send downlink if queued
        └─ Downlink received as "mac_rx <port> <data>"

T=6s    Device enters deep sleep

[If downlink received]
  ├─ Parse port (e.g., port 2 = frequency update)
  ├─ Extract 2-byte interval (big-endian)
  ├─ Update txIntervalMs for next cycle
  └─ Return to sleep
```

### Comparison: LoRaWAN vs. P2P

| Aspect | LoRaWAN Node | P2P Sensor Node |
|---|---|---|
| **Network Type** | Cloud-based LoRaWAN | Local P2P broadcast |
| **Gateway Required** | Loriot only | Main gateway (always-on) |
| **Connectivity** | Anywhere in Loriot coverage | ~1-2 km to main gateway |
| **Device ID** | 0x02AABBCC (cloud-registered) | 0x01AABBCC (local whitelist) |
| **Data Path** | Direct to Loriot cloud | Via gateway to MQTT/cloud |
| **Downlink** | From Loriot backend | From main gateway |
| **Power** | Battery, periodic sleep | Battery, PING-synchronized sleep |
| **Setup** | Register on Loriot + OTAA | Update APPROVED_DEVICE_IDS on gateway |

---

## Data Structures

### LoRaWAN Uplink Payload (13 bytes, port 2)

**Same format as P2P sensor data, but with LoRaWAN encryption**:
```
Bytes 0-3:   Device ID (0x02AABBCC, big-endian)
Bytes 4-5:   Temperature (int16_t / 10, big-endian)
Byte 6:      Humidity (0-100%)
Bytes 7-8:   Lux (big-endian uint16_t)
Bytes 9-10:  Soil Moisture (big-endian uint16_t)
Byte 11:     Water Leak (0x00 or 0x01)
Byte 12:     Battery (0-255%, or raw ADC)

Encryption: Automatic LoRaWAN encryption (AppSKey + NwkSKey)
  └─ RN2483 and Loriot backend handle AES encryption transparently
```

### LoRaWAN Downlink Packet (2+ bytes, port 2)

**Received from Loriot, typically a frequency/sleep update**:
```
Byte 0-1:   TX interval in seconds (big-endian uint16_t)
  Example: [0x00, 0x78] = 120 seconds

Byte 2+:    Optional additional parameters

Decryption: Automatic LoRaWAN decryption (hardware)
```

---

## Execution Flow

### Boot Sequence (First Time)

```
main() [ESP32 bootloader]
  ↓
setup()
  ├─ Initialize Serial (115200 USB debug)
  ├─ Print "LoRaWAN Sensor Node starting..."
  │
  ├─ connectToLoRa()
  │  ├─ Reset RN2483 (GPIO23 pulse)
  │  ├─ Begin UART1 @ 57600 baud
  │  ├─ Get hardware EUI ("sys get hweui")
  │  │  └─ Print to Serial: "HWEUI: 70B3D5XXXXXXXX"
  │  │     [User copies this to Loriot registration]
  │  └─ Print "Register this HWEUI on Loriot"
  │
  ├─ joinLoRaWAN()
  │  ├─ Set APPEUI from code define
  │  ├─ Set APPKEY from code define
  │  ├─ Attempt "mac join otaa"
  │  ├─ Wait up to 10 seconds for "accepted"
  │  │
  │  ├─ If accepted:
  │  │  ├─ Set joined = true
  │  │  ├─ Print "Joined successfully"
  │  │  └─ Proceed to main loop
  │  │
  │  └─ If timeout:
  │     ├─ Set joined = false
  │     ├─ Print "Join failed, retrying in loop"
  │     └─ Retry in loop every iteration
  │
  └─ Print "Node ready"

[Loop begins]
```

### Main Loop (continuous)

```
loop() [runs until sleep interval OR timeout]
  ├─ Check if joined to Loriot:
  │  └─ If not: attempt rejoin
  │
  ├─ Check if time to send uplink:
  │  ├─ If (now - lastTxMs) >= txIntervalMs:
  │  │
  │  ├─ Collect sensor data:
  │  │  ├─ DHT22: temp, humidity
  │  │  ├─ Light sensor: lux
  │  │  ├─ Soil moisture: ADC value
  │  │  ├─ Water leak: boolean
  │  │  └─ Battery: ADC percentage
  │  │
  │  ├─ Build 13-byte payload
  │  ├─ Send uplink:
  │  │  ├─ "mac tx ucnf 2 <hex_payload>"
  │  │  │  (ucnf = unconfirmed, confirmed also available)
  │  │  └─ Wait for "mac_tx_ok"
  │  │
  │  ├─ Listen for Class A downlink (1 second):
  │  │  ├─ If "mac_rx 2 <data>" received:
  │  │  │  ├─ Parse 2-byte interval (big-endian)
  │  │  │  ├─ Update txIntervalMs for next cycle
  │  │  │  └─ Clamp to MIN/MAX range
  │  │  └─ If no downlink: keep current interval
  │  │
  │  └─ Update lastTxMs = millis()
  │
  ├─ If sleep interval enabled:
  │  └─ Check if in sleep window
  │     ├─ If time to sleep:
  │     │  ├─ Print "Entering deep sleep for X seconds"
  │     │  ├─ esp_sleep_enable_timer_wakeup()
  │     │  └─ esp_deep_sleep()
  │     │
  │     └─ CPU wakes after timer, setup() runs again
  │
  └─ Repeat loop (if not sleeping)
```

### Sleep Cycle (if battery-powered)

```
[After uplink TX + downlink RX]
  ├─ Calculate next TX time
  ├─ esp_sleep_enable_timer_wakeup(txIntervalMs * 1e6)
  └─ esp_deep_sleep()
     └─ RTC counter runs, wakes CPU when timer expires
```

---

## Methods Reference

### **Phase 1: Initialization**

#### 1. `connectToLoRa()`
- **Purpose**: Initialize RN2483 LoRaWAN module
- **Called**: Once during setup
- **Parameters**: None
- **Flow**:
  1. Reset RN2483 (GPIO23 pulse)
  2. Begin UART1 @ 57600
  3. Flush serial
  4. Get hardware EUI: "sys get hweui"
  5. Print EUI to Serial (for Loriot registration)
  6. Return success
- **Returns**: bool

#### 2. `joinLoRaWAN()`
- **Purpose**: Perform OTAA join to Loriot LoRaWAN network
- **Called**: Once during setup, retry in loop if failed
- **Parameters**: None
- **Flow**:
  1. Set APPEUI from code define
  2. Set APPKEY from code define
  3. Call myLora.join(OTAA mode)
  4. Wait up to 10 seconds for "accepted"
  5. If joined: set joined = true, return true
  6. If timeout: set joined = false, return false
- **Returns**: bool

---

### **Phase 2: Main Loop**

#### 3. `checkAndSendUplink()` 🎯 **CRITICAL**
- **Purpose**: Check if time to send and transmit sensor data
- **Called**: Every loop iteration
- **Parameters**: None
- **Flow**:
  1. If not joined: attempt rejoin
  2. If (now - lastTxMs) >= txIntervalMs:
     - Collect sensor data
     - Build 13-byte payload
     - Send uplink: "mac tx ucnf 2 <hex>"
     - Wait for "mac_tx_ok"
     - Listen for downlink (1 second window)
     - Update lastTxMs
- **Returns**: bool (true if uplink sent)

#### 4. `collectSensorData(uint8_t* payload)` 📊
- **Purpose**: Read sensors and populate 13-byte uplink payload
- **Called**: By checkAndSendUplink()
- **Parameters**: payload (13-byte buffer to fill)
- **Flow**:
  1. Read DHT22: temp, humidity
  2. Read light sensor: lux
  3. Read soil moisture: ADC
  4. Read water leak: boolean
  5. Read battery: ADC percentage
  6. Pack into 13-byte struct (big-endian)
- **Returns**: void (modifies payload)

#### 5. `sendLoRaUplink(const uint8_t* payload, size_t len)`
- **Purpose**: Send LoRaWAN uplink to Loriot on port 2
- **Called**: By checkAndSendUplink()
- **Parameters**:
  - payload: 13-byte sensor data
  - len: 13
- **Flow**:
  1. Convert payload to hex string
  2. Call myLora.txUncnf(2, hex_payload)
     - port 2 = sensor data uplink
     - ucnf = unconfirmed (no MAC-level ACK)
  3. Wait for "mac_tx_ok"
- **Returns**: bool (true if TX confirmed)

#### 6. `handleDownlink()` 📥
- **Purpose**: Receive and process Class A downlinks
- **Called**: 1 second after uplink TX
- **Parameters**: None
- **Flow**:
  1. Listen for "mac_rx <port> <data>"
  2. If received on port 2:
     - Parse 2-byte interval (big-endian uint16_t)
     - Validate range (MIN_TX_INTERVAL_MS to MAX_TX_INTERVAL_MS)
     - Update txIntervalMs
     - Log to Serial
  3. If received on other port: ignore or log
- **Returns**: void

---

### **Phase 3: LoRa Communication (via rn2xx3 library)**

#### 7. `readLoRaLine(int timeoutMs)`
- **Purpose**: Read one line from RN2483
- **Called**: By join and response reading
- **Parameters**: timeoutMs (timeout)
- **Flow**:
  1. Set timeout
  2. Read chars until '\n'
  3. Return line (or empty if timeout)
- **Returns**: String

#### 8. `sendLoRaCommand(const String& cmd, int timeoutMs)`
- **Purpose**: Send AT command to RN2483
- **Called**: During initialization
- **Parameters**:
  - cmd: AT command
  - timeoutMs: response timeout
- **Flow**:
  1. Print to loraSerial
  2. readLoRaLine()
  3. Return response
- **Returns**: String

---

### **Phase 4: Sensor Reading**

#### 9. `readDHT22(float& temp, uint8_t& humidity)`, `readLightSensor()`, `readSoilMoisture()`, `readWaterLeak()`, `readBattery()`
- **Same as P2P Sensor Node** (see [sensor-node README](../sensor-node/README.md#phase-4-sensor-reading-functions))

---

### **Phase 5: Utility Functions**

#### 10. `bytesToHex()`, `hexToBytes()`, `hexNibble()`, `setLed()`
- **Same as other nodes** (see previous component READMEs)

---

## Communication Protocols

### UART1: RN2483 LoRaWAN Module (57600 baud)

#### AT Command Format (LoRaWAN)
```
Request (Node → RN2483):
  <command>\r\n
  Example: "mac tx ucnf 2 A50149474F50\r\n"

Response (RN2483 → Node):
  <response>\r\n
  Examples:
    "ok\r\n"              (command accepted)
    "accepted\r\n"        (OTAA join successful)
    "mac_tx_ok\r\n"       (uplink transmitted)
    "mac_rx 2 XXXXXX\r\n" (downlink received on port 2)
    "mac_err\r\n"         (error)
```

#### Common Commands (LoRaWAN)
```
OTAA Join:
  sys get hweui           → Hardware EUI (register on Loriot)
  mac set appeui <hex>    → Application EUI (from Loriot)
  mac set appkey <hex>    → Application Key (from Loriot)
  mac join otaa           → Initiate join
  Response: "ok", later "accepted" or timeout

Transmission:
  mac tx ucnf 2 <hex>     → Unconfirmed uplink on port 2
  mac tx cnf 2 <hex>      → Confirmed uplink (waits for ACK)
  Response: "ok" (sent), later "mac_tx_ok" (confirmed)

Reception (automatic, 1 second after TX):
  [RN2483 automatically opens RX windows]
  mac_rx <port> <data>    → Downlink received on port
```

---

## Setup & Deployment

### Prerequisites

#### Loriot Account & Device Registration
1. **Visit iotnet.teracom.dk**
2. **Create account** and log in
3. **Register new device**:
   - Select "OTAA" mode
   - Click "Generate all except DevEUI"
   - Leave HWEUI field empty (will fill from device)
4. **Note the APPEUI and APPKEY** displayed

#### Flash the Device to Get HWEUI
1. **Upload firmware** to ESP32
2. **Open Serial Monitor** (115200 baud)
3. **Copy HWEUI** from output:
   ```
   LoRaWAN Sensor Node starting...
   HWEUI: 70B3D5XXXXXXXX
   Register this HWEUI on Loriot
   ```
4. **Return to Loriot**:
   - Fill in HWEUI field with copied value
   - Device is now registered

### Configuration

**File**: [lorawan-sensor-node/lorawan-sensor-node.cpp](lorawan-sensor-node.cpp) (lines 28-35)

```cpp
static const char* APPEUI = "0123456789ABCDEF";
static const char* APPKEY = "0123456789ABCDEF0123456789ABCDEF";

#define DEVICE_ID             0x02AABBCC
#define DEFAULT_TX_INTERVAL_MS 30000UL   // 30 seconds
#define MIN_TX_INTERVAL_MS     30000UL   // 30 sec minimum
#define MAX_TX_INTERVAL_MS   3600000UL   // 60 min maximum
```

### Flashing Procedure

```
Board: ESP32 Dev Module
Upload Speed: 921600
Port: COM[your device]
File: lorawan-sensor-node/lorawan-sensor-node.cpp
```

### Verification

**Serial Monitor Output** (115200 baud):
```
LoRaWAN Sensor Node starting...
HWEUI: 70B3D5XXXXXXXX
[Copy this to Loriot]

RN2483 connected.
Attempting LoRaWAN join (OTAA)...
Sending: mac join otaa
[Waiting for accepted...]
Joined successfully!

[Every 30 seconds]
Collecting sensors...
Temperature: 23.5°C
Humidity: 65%
Lux: 150
Soil: 512
Battery: 92%

Sending uplink on port 2...
Uplink: A50149474F50...
TX complete.
Listening for downlink (1 second)...
[No downlink]
Next uplink in 30s.

[If downlink received]
Downlink received on port 2: 0078
Parsed TX interval: 120 seconds
Updated next uplink interval.
```

**Loriot Backend**:
- Navigate to device page on iotnet.teracom.dk
- View "Recent Messages" → should show your 13-byte payloads
- Each uplink contains device ID (0x02AABBCC) + sensor data

---

## Remote Control via Downlinks

To change TX interval from Loriot dashboard:

1. **On device page**: Go to "Send downlink"
2. **Port**: 2
3. **Data (hex)**: Enter 2-byte interval
   - `0078` = 120 seconds
   - `00F0` = 240 seconds
   - `0E10` = 3600 seconds (1 hour)
4. **Send**

Device will receive on next RX window (1 second after next uplink) and update interval.

---

## Summary

The **LoRaWAN Sensor Node** provides cloud-native environmental monitoring by:

| Aspect | Detail |
|---|---|
| **Network** | LoRaWAN (Loriot, EU868) |
| **Device ID** | 0x02AABBCC (MSB 0x02 = LoRaWAN type) |
| **Uplink Interval** | 30-3600 seconds (configurable via downlink) |
| **Power** | Battery with periodic deep sleep |
| **Encryption** | LoRaWAN AES (automatic) |
| **Downlinks** | Class A, 1 second after TX |
| **Independence** | Works without main gateway |

**Key Differences from P2P Node**:
- ✅ Direct cloud connectivity (no gateway bridge needed)
- ✅ Official LoRaWAN standard encryption
- ✅ Works anywhere in Loriot coverage
- ❌ No local gateway backup
- ❌ Slower response (polling-based, not event-driven)

**Use Case**: 
- Long-term cloud data logging
- Coverage in remote areas (Loriot has better coverage than local P2P)
- Integration with LoRaWAN-native platforms (Loriot, TTN)
- Backup path when main gateway is offline

See [Main Gateway Documentation](../gateway/README.md) for complete system architecture.

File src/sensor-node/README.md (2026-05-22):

# ESP32 Sensor Node - Battery-Powered Environmental Monitor

## Table of Contents
1. [System Overview](#system-overview)
2. [Hardware Architecture](#hardware-architecture)
3. [Integration with Gateway](#integration-with-gateway)
4. [Data Structures](#data-structures)
5. [Execution Flow](#execution-flow)
6. [Methods Reference & Execution Order](#methods-reference--execution-order)
7. [Communication Protocols](#communication-protocols)
8. [Setup & Deployment](#setup--deployment)

---

## System Overview

### Purpose
The **Sensor Node** is a battery-powered environmental monitoring device that wakes periodically to collect sensor data and transmit it to the gateway. It implements aggressive power management, sleeping 99% of the time to maximize battery life.

### Key Responsibilities
- **Periodic Wake-Up**: Listen for gateway PING on schedule
- **Sensor Readings**: Collect temperature, humidity, light, soil moisture, water leak, and battery voltage
- **Data Transmission**: Encode 13-byte payload and transmit via LoRa P2P
- **Command Reception**: Listen for light control and sleep interval updates from gateway
- **Sleep Management**: Return to deep sleep with gateway-provided interval (10-65000 seconds)
- **Battery Efficiency**: Sleep ~99% of runtime; active for <1 second per cycle

### When to Use
- **Distributed monitoring**: Multiple sensor nodes across greenhouse
- **Long battery life**: 2×AA batteries last 6-12 months in normal operation
- **Wireless**: No wiring required, nodes can be placed anywhere in range
- **Scalable**: Add more nodes without changing gateway code (just update APPROVED_DEVICE_IDS)

---

## Hardware Architecture

### Main Components

#### **ESP32 Microcontroller (Sensor Node)**
- **Role**: Main control board with sensors
- **Power**: 2×AA Battery (~3V), deep sleep mode to minimize consumption
- **UART Ports**:
  - **UART1** (pins 16/17): Connected to RN2483 LoRa module at 57600 baud
  - **UART0** (USB): USB Serial for debugging at 115200 baud (programming only)
- **Sensors**:
  - **GPIO4**: DHT22 (temperature/humidity) digital sensor
  - **GPIO34**: KY-018 photoresistor (analog light sensor)
  - **GPIO35**: Capacitive soil moisture sensor (analog)
  - **GPIO33**: Water leak detector (analog or digital)
  - **I2C (GPIO21/22)**: Optional OLED display (128x64 SH1106)
- **Sleep**:
  - **RTC Memory**: Stores device ID, sync state, sleep duration across deep sleep
  - **Timer**: Wakeup on interval (set by gateway)

#### **RN2483 LoRa Module (P2P)**
- **Communication**: Connected via UART1 at 57600 baud
- **Protocol**: LoRa P2P (not LoRaWAN, proprietary mode)
- **Frequency**: 868.1 MHz (European ISM band)
- **Purpose**: Receive PING from gateway, transmit sensor data
- **Interface**: AT command protocol
  - Commands: `radio rx`, `radio tx`, `radio set`, `mac pause`
  - Responses: `ok`, `radio_rx <hex>`, `radio_tx_ok`, `radio_err`

### Pin Mapping

```
ESP32 (Sensor Node) Pin Configuration:
├─ UART1 (LoRa P2P):
│  ├─ GPIO16 (RX) <- RN2483 TX
│  └─ GPIO17 (TX) -> RN2483 RX
├─ GPIO14: RN2483 Reset (active-low)
├─ GPIO2: LED (activity indicator)
├─ Analog Sensors:
│  ├─ GPIO34: Light sensor (analog in)
│  ├─ GPIO35: Soil moisture (analog in)
│  └─ GPIO33: Water leak (analog or digital in)
├─ GPIO4: DHT22 data line
├─ I2C (Optional OLED):
│  ├─ GPIO21: SDA
│  ├─ GPIO22: SCL
│  └─ Adafruit SH1106 128x64 display
└─ UART0 (USB Serial @ 115200):
   └─ Used for Serial.print() debugging during development

Power Pins:
├─ 3.3V: Battery (via voltage regulator)
└─ GND: Battery return

Baud Rates:
├─ UART1: 57600 (RN2483 standard)
└─ USB Serial: 115200 (debugging)
```

### Power Consumption Profile

```
State          Duration    Current    Energy Per Cycle
─────────────────────────────────────────────────────
Deep Sleep     118.5s      ~3 µA      ~0.35 µJ
Wake CPU       0.5s        ~100 mA    ~50 µJ (reading sensors)
RX (Listen)    12s         ~100 mA    ~12 mJ
TX (Send)      0.5s        ~600 mA    ~0.3 mJ
─────────────────────────────────────────────────────
Total Cycle    120s        ~3 µA avg  ~12.5 mJ / cycle

Typical Battery Life (2×AA, 2500 mAh each):
  Total capacity: ~2.5 * 3600 = 9000 C (coulombs)
  Cycles: 9000 / (12.5 mJ / 3V) = ~432,000 cycles
  Duration: 432,000 cycles * 120s = 50.4 million seconds ≈ 585 days (~19 months)
```

---

## Integration with Gateway

### Wake Cycle Orchestration

```
T=0min    Gateway sends PING broadcast (every 120 seconds)
          └─ 8-byte: [0x50,0x49,0x4E,0x47] + [SHARED_KEY]
          └─ Encrypted with XOR
          └─ Broadcasts on 868.1 MHz

T=0-12s   Sensor Node Listening Window
          ├─ ESP32 in deep sleep (RN2483 stays powered, in RX mode)
          ├─ RN2483 radio interrupt wakes CPU if PING received
          ├─ If PING valid (header + key match):
          │  └─ MCU wakes, begins sensor collection
          └─ If PING not received:
             └─ Sleep again (sync lost, retry next cycle)

T=1-3s    Sensor Data Collection
          ├─ Read DHT22: temperature, humidity
          ├─ Read TSL2561: ambient light (lux)
          ├─ Read capacitive sensor: soil moisture
          ├─ Read GPIO: water leak detector
          ├─ Read ADC: battery voltage
          └─ Pack into 13-byte struct

T=3-4s    Sensor Data Transmission
          ├─ Build 13-byte payload
          ├─ XOR encrypt with SHARED_KEY
          ├─ Convert to 26-char hex string
          ├─ Send: "radio tx <hex>"
          └─ Wait for "radio_tx_ok"

T=4-8s    Listen for Light Command
          ├─ Enter RX mode: "radio rx 0" (POST_TX_RX_MS = 8 seconds)
          ├─ If "radio_rx <hex>" received:
          │  ├─ Decrypt with XOR
          │  ├─ Parse: device ID, desired lux, next sleep seconds
          │  └─ Update rtcSleepSeconds (RTC memory for next cycle)
          └─ If no RX: use DEFAULT_SLEEP_S

T=8s      Return to Deep Sleep
          ├─ Store rtcSleepSeconds in RTC memory
          ├─ esp_sleep_enable_timer_wakeup(rtcSleepSeconds * 1e6)
          ├─ esp_deep_sleep()  [CPU powered off]
          └─ RN2483 may remain powered or enter sleep (implementation dependent)

T=120s    Gateway sends next PING (cycle repeats)
```

### Initialization Flow (First Boot vs. Sync Loss)

```
FIRST BOOT (rtcSyncedWithGateway = false):
  ├─ Listen for FIRST_SYNC_PING_WAIT_MS (130 seconds)
  └─ If PING not received within 130s:
     └─ Sleep for shorter interval, retry more often

NORMAL OPERATION (rtcSyncedWithGateway = true):
  ├─ Listen for PING_WAIT_MS (12 seconds)
  └─ If PING received:
     └─ Use gateway-provided sleep interval

SYNC LOSS (PING not received in expected window):
  ├─ Fall back to DEFAULT_SLEEP_S (115 seconds)
  ├─ Retry next cycle
  └─ Re-establish sync when PING arrives
```

---

## Data Structures

### SensorReading (13 bytes)

**Transmitted from sensor to gateway**:
```
struct SensorReading {
  int16_t  tempTenthsC;      // 2 bytes, tenths of °C (e.g., 235 = 23.5°C)
  uint8_t  humidity;          // 1 byte, 0-100%
  uint16_t lux;              // 2 bytes, light level (0-65535)
  uint16_t soilMoistureRaw;  // 2 bytes, capacitive ADC (0-4095)
  bool     waterLeak;         // 1 byte, false=0 or true=1
  uint8_t  battery;           // 1 byte, battery percentage (0-100%) or raw ADC
};

Binary Layout (13 bytes total):
Byte 0-3:   Device ID (0x01AABBCC, big-endian)
Byte 4-5:   Temperature (big-endian int16_t)
Byte 6:     Humidity
Byte 7-8:   Lux (big-endian uint16_t)
Byte 9-10:  Soil Moisture (big-endian uint16_t)
Byte 11:    Water Leak
Byte 12:    Battery

Encryption: XOR with SHARED_KEY before TX
```
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

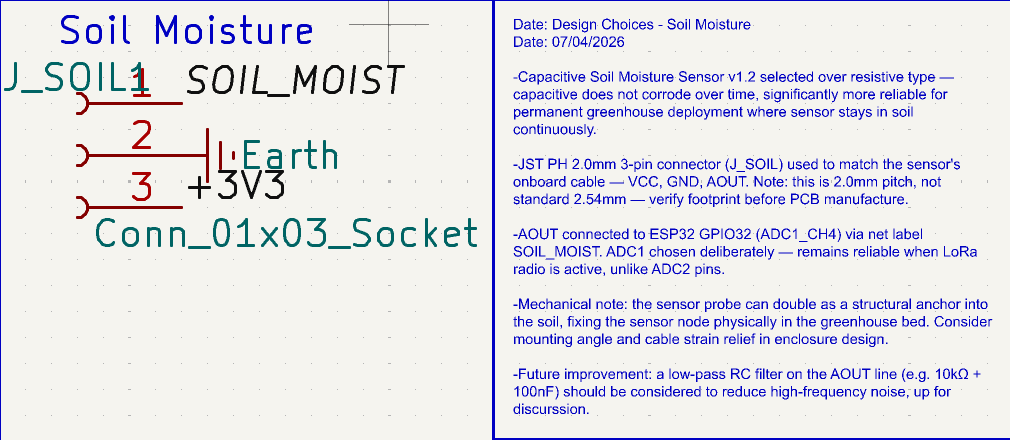
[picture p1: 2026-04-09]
docs/images/pcb/SENSORS/SOIL.png

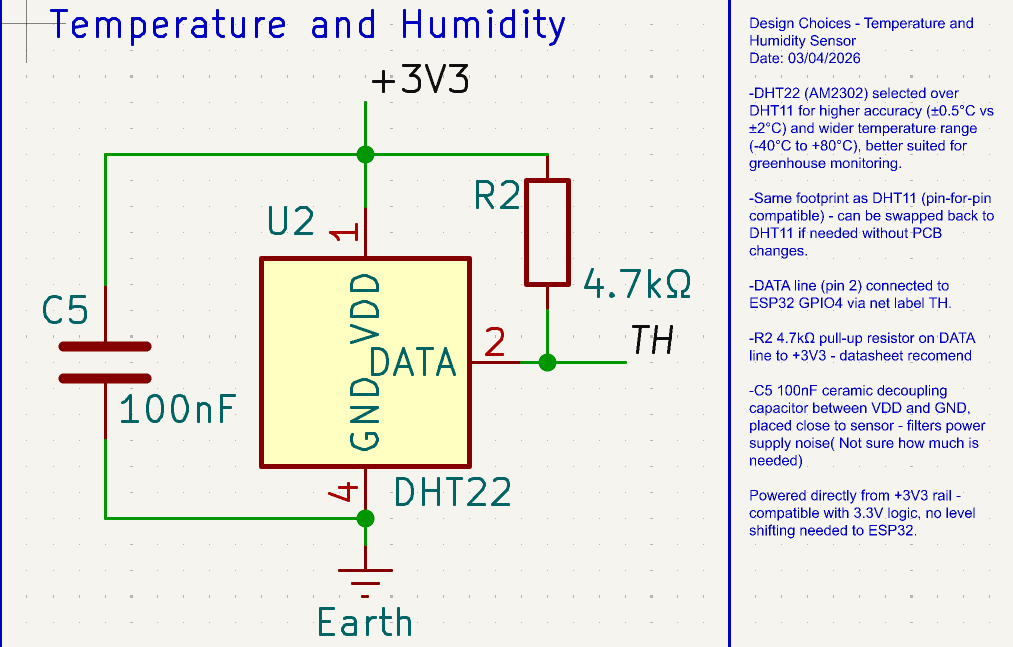
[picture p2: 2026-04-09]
docs/images/pcb/SENSORS/TH.png

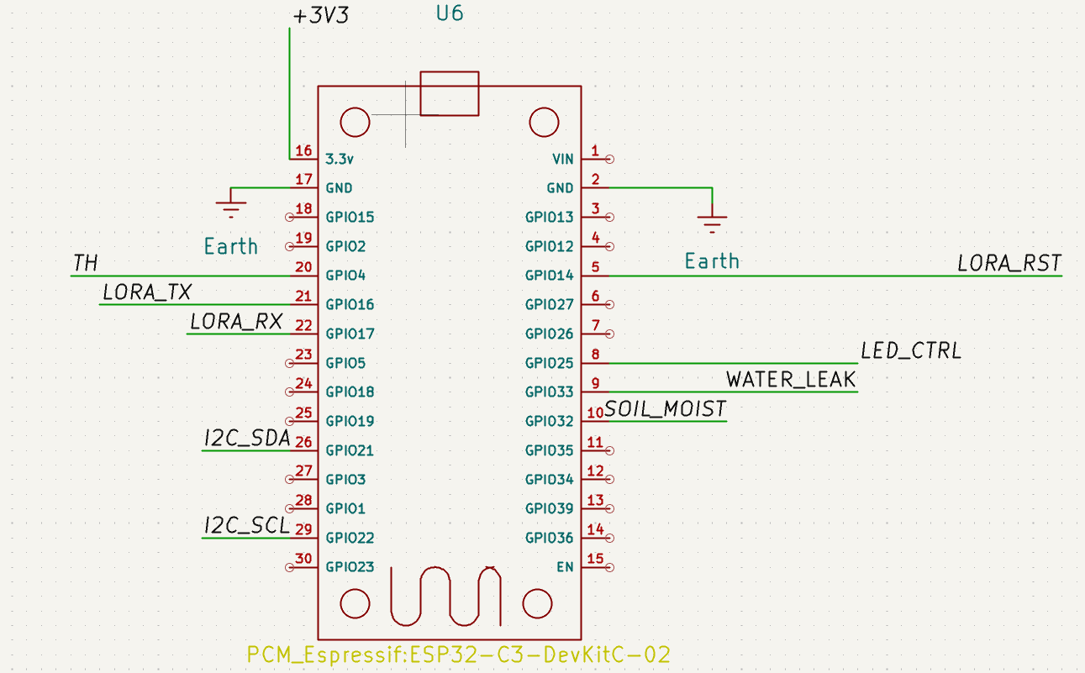
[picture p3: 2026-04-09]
docs/images/pcb/MCU/MCU.png

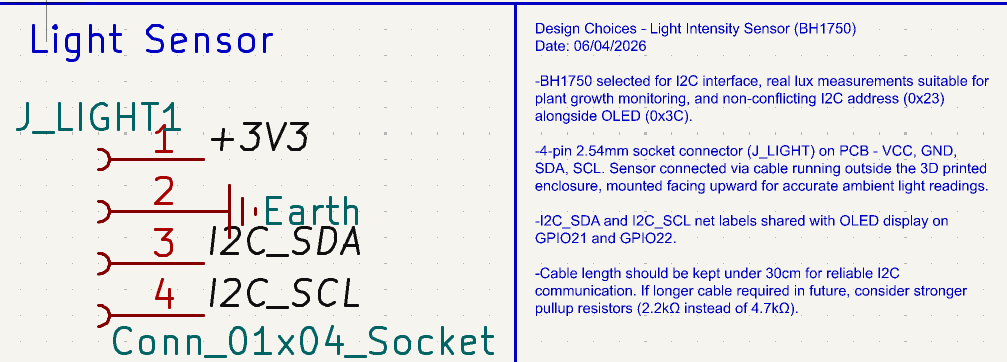
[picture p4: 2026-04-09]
docs/images/pcb/SENSORS/LIGHT.png

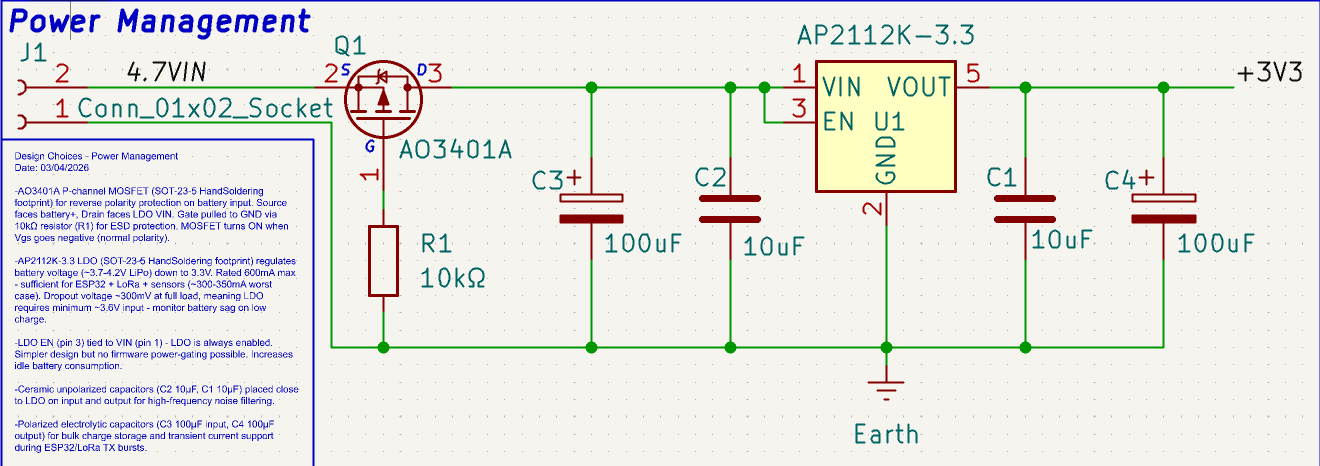
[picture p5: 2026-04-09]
docs/images/pcb/POWER/Power Management.png

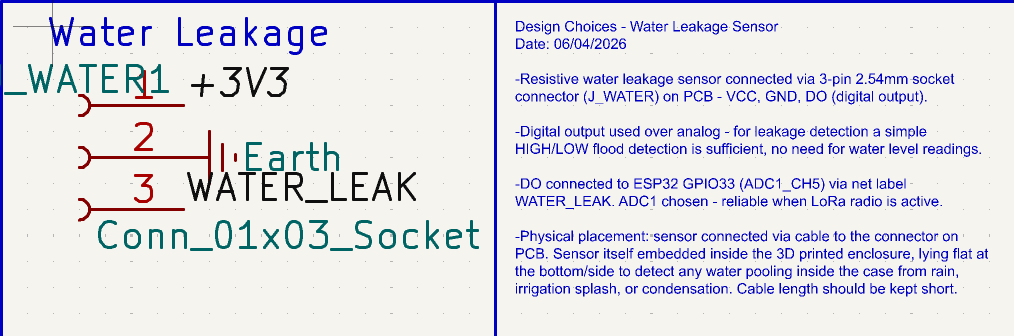
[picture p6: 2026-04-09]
docs/images/pcb/SENSORS/WATER.png

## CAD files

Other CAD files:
docs/hardware/3DCASE/iotcase.f3d

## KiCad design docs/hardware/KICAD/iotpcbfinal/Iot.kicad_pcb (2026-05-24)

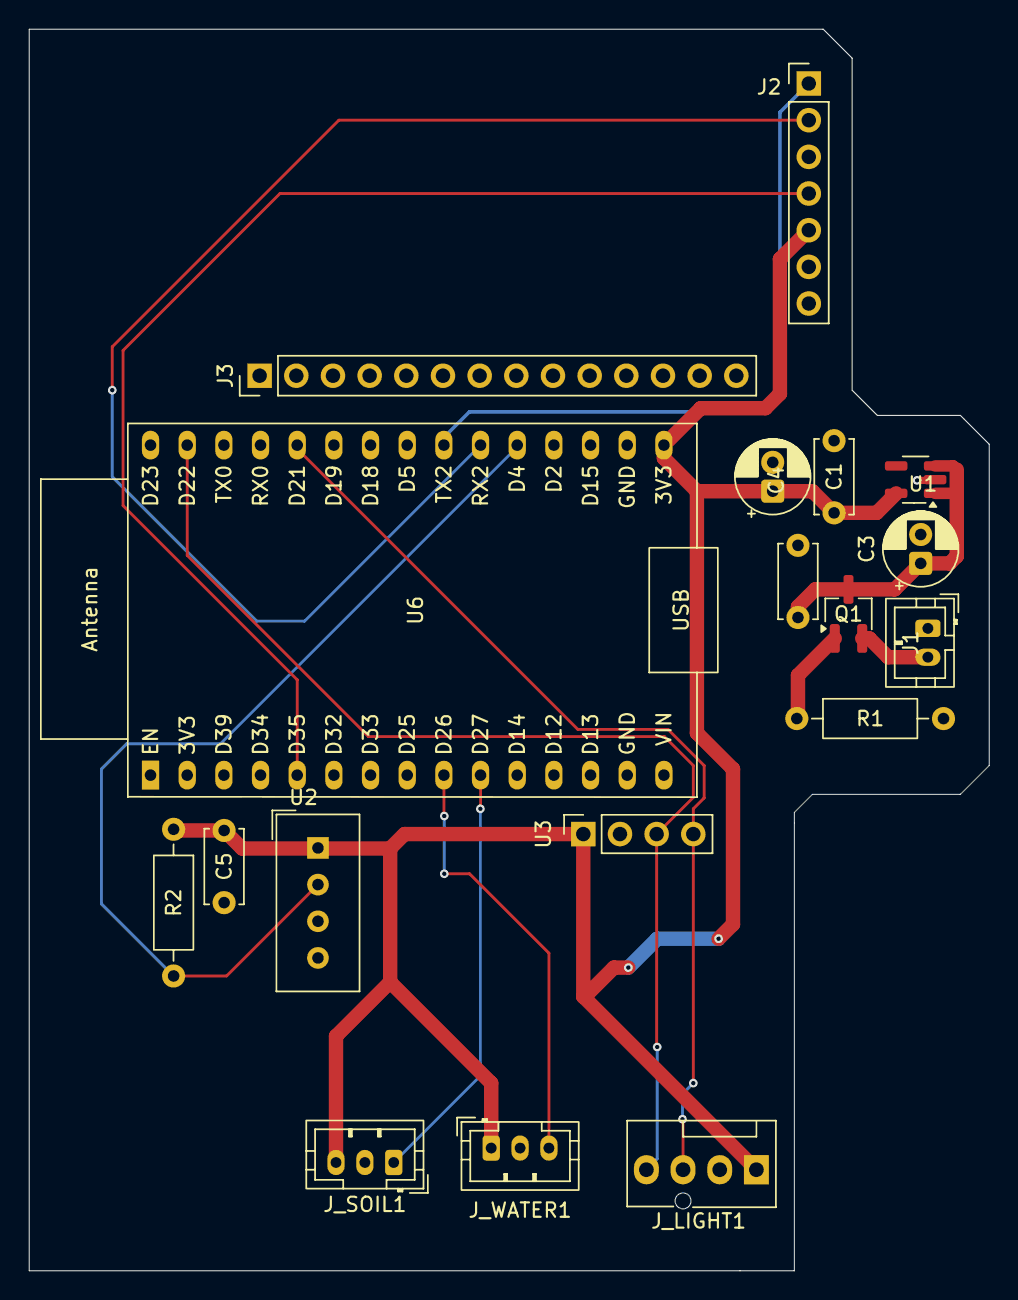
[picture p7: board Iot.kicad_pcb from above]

Board: 2 copper layers, 66.5 x 86.0 mm, 18 parts (0 on the bottom side), 13 nets.

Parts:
C1, C2: 10uF; C_Disc_D5.0mm_W2.5mm_P5.00mm
C3, C4: 100uF; CP_Radial_D5.0mm_P2.00mm
C5: 100nF; C_Disc_D5.0mm_W2.5mm_P5.00mm
J1: Conn_01x02_Socket; JST_PH_B2B-PH-K_1x02_P2.00mm_Vertical
J2: Conn_01x07_Socket; PinHeader_1x07_P2.54mm_Vertical
J3: Conn_01x14_Socket; PinHeader_1x14_P2.54mm_Vertical
J_LIGHT1: Conn_01x04_Socket; FanPinHeader_1x04_P2.54mm_Vertical
J_SOIL1: Conn_01x03_Socket; JST_PH_B3B-PH-K_1x03_P2.00mm_Vertical
J_WATER1: Conn_01x03_Socket; JST_PH_B3B-PH-K_1x03_P2.00mm_Vertical
Q1: AO3401A; SOT-23W_Handsoldering
R1: 10kΩ; R_Axial_DIN0207_L6.3mm_D2.5mm_P10.16mm_Horizontal
R2: 4.7kΩ; R_Axial_DIN0207_L6.3mm_D2.5mm_P10.16mm_Horizontal
U1: AP2112K-3.3; SOT-23-5_HandSoldering
U2: DHT11; Aosong_DHT11_5.5x12.0_P2.54mm
U3: ER_OLEDM0.91_1x-I2C; PinSocket_1x04_P2.54mm_Vertical
U6: ESP32-C3-DevKitC-02

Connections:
/4.7VIN: J1.2, Q1.2 (S)
/+3V3: C1.1, C4.1, C5.1, J2.5, J_LIGHT1.1, J_SOIL1.3, J_WATER1.1, R2.1, U1.5 (VOUT), U2.1 (VDD), U3.2 (VCC), U6.16 (3.3v)
/I2C_SCL: J_LIGHT1.4, U3.3 (SCL), U6.29 (GPIO22)
/I2C_SDA: J_LIGHT1.3, U3.4 (SDA), U6.26 (GPIO21)
/LORA_RST: J2.4, U6.5 (GPIO14)
/LORA_RX: J2.1, U6.22 (GPIO17)
/LORA_TX: J2.2, U6.21 (GPIO16)
/SOIL_MOIST: J_SOIL1.1, U6.10 (GPIO32)
/TH: R2.2, U2.2 (DATA), U6.20 (GPIO4)
/WATER_LEAK: J_WATER1.3, U6.9 (GPIO33)
Earth: C1.2, C2.2, C3.2, C4.2, C5.2, J1.1, J2.7, J_LIGHT1.2, J_SOIL1.2, J_WATER1.2, R1.2, U1.2 (GND), U2.4 (GND), U3.1 (GND), U6.17 (GND)
unnamed: C2.1, C3.1, Q1.3 (D), U1.1 (VIN), U1.3 (EN)
unnamed: Q1.1 (G), R1.1

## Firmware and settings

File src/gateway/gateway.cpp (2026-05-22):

/*

  Board: ESP32 (DevKit / WROOM)
  Role:  Gateway / receiver. Sits on WiFi + MQTT, talks to RN2483 over UART1.
         Sends wake pings to sensor nodes, receives 13-byte sensor payloads,
         publishes them as JSON to the dashboard, and tells nodes when the
         plant needs more light.

  Flow:
    boot -> WiFi -> MQTT -> init RN2483 -> loop:
      keep WiFi/MQTT alive, send periodic ping, listen for sensor reply,
      publish JSON, optionally send light command back.

  Test:
    1. Flash, open Serial Monitor at 115200.
    2. Wait for "WiFi connected" + "MQTT connected" + "Gateway ready".
    3. Subscribe to esp32/myroom123/status with mosquitto_sub or MQTT Explorer.
    4. Publish "PING" to esp32/myroom123/ping to force a wake-up ping.
    5. The sensor node should reply within a few seconds; JSON shows up.


*/

#include <Arduino.h>
#include <WiFi.h>
#include <PubSubClient.h>
#include <HardwareSerial.h>

// ---------- WiFi / MQTT ----------
#define WIFI_SSID       "WIFI"
#define WIFI_PASSWORD   "PASS"

#define MQTT_BROKER     "broker.emqx.io"
#define MQTT_PORT       1883

#define TOPIC_CONTROL   "esp32/myroom123/control"
#define TOPIC_STATUS    "esp32/myroom123/status"
#define TOPIC_PING      "esp32/myroom123/ping"

// ---------- Pins ----------
#define LED_PIN           4
#define LORA_UART_RX_PIN  16   // GPIO16 <- RN2483 TX
#define LORA_UART_TX_PIN  17   // GPIO17 -> RN2483 RX
#define RN2483_RST_PIN    2
#define SLAVE_UART_RX_PIN 18   // GPIO18 <- gateway_slave TX (GPIO17)
#define SLAVE_UART_TX_PIN 19   // GPIO19 -> gateway_slave RX (GPIO16)

// ---------- Slave bridge UART ----------
#define SLAVE_BAUD_RATE   115200UL

// ---------- LoRa radio settings (must match sensor node) ----------
#define LORA_BAUD_RATE   57600UL       // Serial baud rate for RN2483 LoRa module communication
#define LORA_FREQ        868100000UL   // LoRa frequency in Hz; working TX/RX pair uses 868.1 MHz
#define LORA_PWR         14            // LoRa transmit power in dBm
#define LORA_SF          "sf12"        // LoRa spreading factor (SF12 = max range, slowest speed)
#define LORA_AFCBW       "41.7"        // AFC (Automatic Frequency Correction) bandwidth in kHz
#define LORA_RXBW        125           // RX bandwidth in kHz (125 kHz standard)
#define LORA_PRLEN       8             // LoRa preamble length in symbols
#define LORA_CRC         "on"          // Enable CRC (Cyclic Redundancy Check) for packet integrity
#define LORA_IQI         "off"         // IQ inversion disabled for normal operation
#define LORA_CR          "4/5"         // Coding rate (4/5 = 4 info bits per 5 total transmitted bits)
#define LORA_SYNC        "12"          // LoRa sync word (used as device network identifier)
#define LORA_BW          125           // Bandwidth in kHz (125 kHz)
#define LORA_WDT         60000UL       // RX watchdog timeout in ms; 0 = no timeout

// ---------- Protocol ----------
static const uint8_t LORA_PING_HEADER[4] = { 0x50, 0x49, 0x4E, 0x47 };  // "PING"
#define LORA_PING_BYTES          8   // header (4) + shared key (4)
#define SENSOR_PAYLOAD_BYTES     13
#define SENSOR_PAYLOAD_HEX_CHARS 26
#define LIGHT_CMD_BYTES          8

// Light control node protocol:
// 4 bytes device ID + 1 byte command/status.
// For device ID 5:
//   0000000501 = light ON command or ACK OK
//   0000000500 = light OFF command or ACK FAIL
#define LIGHT_NODE_ID            5UL
#define LIGHT_CONTROL_BYTES      5
#define CMD_LIGHT_OFF            0x00
#define CMD_LIGHT_ON             0x01
#define ACK_FAIL                 0x00
#define ACK_OK                   0x01

// ---------- Shared secret ----------
// Must match transmitter. XOR-obfuscates payloads; not cryptographically strong
// but filters out noise and rogue nodes that don't know the key.
static const uint8_t SHARED_KEY[4] = { 0xA3, 0x7F, 0x2C, 0x91 };

// ---------- Approved sensor node device IDs ----------
// Approved sensor node device IDs. Add each node's DEVICE_ID here.
//Static ID 
static const uint32_t APPROVED_DEVICE_IDS[] = {
  0x01AABBCC   // sensor node 1
};
static const int APPROVED_DEVICE_COUNT =
    (int)(sizeof(APPROVED_DEVICE_IDS) / sizeof(APPROVED_DEVICE_IDS[0]));

bool isApprovedDevice(uint32_t id) {
  for (int i = 0; i < APPROVED_DEVICE_COUNT; i++) {
    if (APPROVED_DEVICE_IDS[i] == id) return true;
  }
  return false;
}

// ---------- Timing ----------
#define PING_INTERVAL_MS         120000UL   // auto-ping every 2 min (test)
#define POST_PING_WAIT_MS        10000UL    // listen this long for a sensor reply
#define HEARTBEAT_INTERVAL_MS    60000UL    // send periodic heartbeat status to MQTT broker every 60 sec
#define MQTT_RECONNECT_INTERVAL  3000UL     // attempt MQTT reconnection every 3 sec if dropped
#define BOOT_OVERHEAD_MS         3000UL     // allow 3 sec for sensor node to boot after wake signal
#define MIN_SLEEP_S              10UL       // minimum sleep duration in seconds (safety floor)
#define MAX_SLEEP_S              65000UL    // maximum sleep duration in seconds (stays within 16-bit limit)
#define MANUAL_PING_TIMEOUT_MS   150000UL   // total timeout window for manual MQTT-triggered ping retries
#define RETRY_INTERVAL_MS        15000UL    // delay between retry attempts when manual ping fails
#define ACK_TIMEOUT_MS           5000UL     // timeout waiting for light node to acknowledge command
// Small gap before sending the light command, so the sensor node's
// post-TX RX window is definitely open by the time we transmit.
#define LIGHT_CMD_PRE_DELAY_MS   400        // delay in ms before TX light command after sensor reply TX completes

#define LIGHT_THRESHOLD_LUX      200        // lux level below which plant needs additional light
#define DESIRED_LUX_WHEN_DARK    500        // target lux to maintain when ambient light is insufficient

WiFiClient    espClient;
PubSubClient  mqttClient(espClient);
HardwareSerial loraSerial(1);    // Bridge to mode
HardwareSerial slaveSerial(2);   // UART2: bridge to gateway_slave (pins 18/19)

bool loraReady = false;
bool ledState  = false;
bool lightControlState = false;

unsigned long lastPingTime = 0;
unsigned long lastHeartbeatTime = 0;
unsigned long lastMqttReconnectAttempt = 0;

void xorWithKey(uint8_t* data, size_t len) { // Ofoscates the data but relatively simple 
  for (size_t i = 0; i < len; i++) {
    data[i] ^= SHARED_KEY[i % 4]; //Cycles through the 4-byte key repeatedly (key repeats every 4 bytes)
  }
}

struct SensorData {
  uint32_t deviceId;
  float    temperature;
  uint8_t  humidity;
  uint16_t lux;
  uint16_t soilMoisture;
  bool     waterLeak;
  uint8_t  battery;
};


// WiFi / MQTT functions
void connectToWiFi();                                                        // Establish initial WiFi connection
void ensureWiFiConnected();                                                  // Retry WiFi if connection drops
bool connectToMQTT();                                                        // Connect to MQTT broker and subscribe to topics
void mqttCallback(char* topic, byte* payload, unsigned int length);         // Handle incoming MQTT messages (ping/control commands)
void publishHeartbeat();                                                     // Send periodic uptime/status message to MQTT
void publishStatus(const String& msg);                                       // Publish a status message to MQTT and Serial
void publishLightControlState();                                             // Publish current LED state as JSON to MQTT
void setLed(bool on);                                                        // Turn gateway LED on/off and log status
void handleSerialLightControlInput();                                        // Handle manual LED control from USB Serial (test shortcut)

// Slave gateway communication (UART2 bridge)
void sendToSlave(const String& cmd);                                         // Send command to gateway-slave over UART2
void handleSlaveSerial();                                                    // Read and process responses from gateway-slave

// LoRa radio control
bool   initLoRa();                                                           // Initialize RN2483 module and configure LoRa parameters
String sendLoRaCommand(const String& cmd, int timeoutMs);                   // Send AT command to RN2483 and get response
String readLoRaLine(int timeoutMs);                                         // Read one line of text from RN2483 with timeout
void   flushLoRaInput();                                                     // Clear any pending data in LoRa serial buffer
void   stopRx();                                                             // Stop active RX listening on LoRa radio

// Sensor ping and communication
bool sendPing(const char* reason);                                           // Send wake-up PING to sensor nodes
bool manualPingWithRetry();                                                  // Retry PING sequence when triggered via MQTT
bool waitForSensorReply(int timeoutMs);                                      // Listen for sensor node reply after sending PING
bool parseSensorPayload(const String& hexStr, SensorData& out);             // Decode 13-byte hex sensor payload into struct
void publishSensorData(const SensorData& d, bool needsLight);               // Format sensor data as JSON and publish to MQTT
uint16_t calculateNextSleepSeconds();                                        // Calculate next sleep interval for sensor node
bool sendLightCommand(uint32_t targetDeviceId, uint16_t desiredLux, uint16_t nextSleepS); // Send lux & sleep data to sensor node
bool sendLightControlCmd(bool turnOn);                                       // Send LED on/off command to light node via LoRa
int  waitForLightAck(bool turnOn);                                           // Wait for light node to acknowledge command (returns 1=OK, 0=FAIL, -1=timeout)
String makeDevicePacket(uint32_t deviceId, uint8_t value);                  // Create device ID + value packet and XOR encrypt it

// Utility functions
bool isApprovedDevice(uint32_t id);                                          // Check if device ID is in whitelist
bool   hexToBytes(const String& hexStr, uint8_t* out, size_t outLen);       // Convert hex string to byte array
String bytesToHex(const uint8_t* data, size_t len);                         // Convert byte array to hex string
int    hexNibble(char c);                                                    // Convert single hex character to 0-15 value
void xorWithKey(uint8_t* data, size_t len);                                 // XOR encrypt/decrypt data with SHARED_KEY


// =================================================================
void setup() {
  Serial.begin(115200);
  delay(100);

  pinMode(LED_PIN, OUTPUT);
  setLed(false);

  Serial.println();
  Serial.println("=== Greenhouse Gateway starting ===");

  connectToWiFi();

  mqttClient.setServer(MQTT_BROKER, MQTT_PORT);
  mqttClient.setBufferSize(512);
  mqttClient.setCallback(mqttCallback);

  if (!initLoRa()) {
    Serial.println("RN2483 init failed. Halting (gateway must not run with broken radio).");
    while (true) { delay(1000); }
  }

  slaveSerial.begin(SLAVE_BAUD_RATE, SERIAL_8N1, SLAVE_UART_RX_PIN, SLAVE_UART_TX_PIN);

  lastPingTime      = millis();
  lastHeartbeatTime = millis();
  Serial.println("Gateway ready.");
}

// Gateway never sleeps. Keep WiFi/MQTT alive, ping periodically,
// listen briefly for a reply after each ping.
void loop() {
  ensureWiFiConnected();

  unsigned long now = millis();

  if (WiFi.status() == WL_CONNECTED) {
    if (!mqttClient.connected()) {
      if (now - lastMqttReconnectAttempt >= MQTT_RECONNECT_INTERVAL) {
        lastMqttReconnectAttempt = now;
        connectToMQTT();
      }
    } else {
      mqttClient.loop();

      if (now - lastHeartbeatTime >= HEARTBEAT_INTERVAL_MS) {
        lastHeartbeatTime = now;
        publishHeartbeat();
      }
    }
  }

  // Scheduled ping
  if (now - lastPingTime >= PING_INTERVAL_MS) {
    lastPingTime = now;
    sendPing("scheduled");
  }

  handleSerialLightControlInput();
  handleSlaveSerial();
}

void connectToWiFi() {
  Serial.print("Connecting to WiFi: ");
  Serial.println(WIFI_SSID);

  WiFi.mode(WIFI_STA);
  WiFi.begin(WIFI_SSID, WIFI_PASSWORD);

  unsigned long start = millis();
  while (WiFi.status() != WL_CONNECTED && millis() - start < 20000UL) {
    Serial.print(".");
    delay(500);
  }
  Serial.println();

  if (WiFi.status() == WL_CONNECTED) {
    Serial.print("WiFi connected, IP: ");
    Serial.println(WiFi.localIP());
  } else {
    Serial.println("WiFi timeout — will keep retrying in loop().");
  }
}

void ensureWiFiConnected() {
  static unsigned long lastRetry = 0;
  if (WiFi.status() == WL_CONNECTED) return;

  unsigned long now = millis();
  if (now - lastRetry >= 5000UL) {
    lastRetry = now;
    Serial.println("WiFi dropped. Reconnecting...");
    WiFi.disconnect();
    WiFi.begin(WIFI_SSID, WIFI_PASSWORD);
  }
}

bool connectToMQTT() {
  if (WiFi.status() != WL_CONNECTED) return false;

  String clientId = "ESP32Gateway-";
  clientId += String((uint32_t)(ESP.getEfuseMac() & 0xFFFFFFFF), HEX);

  Serial.print("MQTT connect to ");
  Serial.print(MQTT_BROKER);
  Serial.print(":");
  Serial.println(MQTT_PORT);

  if (mqttClient.connect(clientId.c_str())) {
    Serial.println("MQTT connected");
    mqttClient.subscribe(TOPIC_CONTROL);
    mqttClient.subscribe(TOPIC_PING);
    mqttClient.publish(TOPIC_STATUS, "ESP32 connected to MQTT broker");
    return true;
  }

  Serial.print("MQTT connect failed, rc=");
  Serial.println(mqttClient.state());
  return false;
}

void mqttCallback(char* topic, byte* payload, unsigned int length) {
  String msg;
  msg.reserve(length);
  for (unsigned int i = 0; i < length; i++) msg += (char)payload[i];
  msg.trim();

  Serial.print("MQTT [");
  Serial.print(topic);
  Serial.print("]: ");
  Serial.println(msg);

  String t(topic);

  if (t == TOPIC_PING) {
    if (msg.equalsIgnoreCase("PING")) {
      bool ok = manualPingWithRetry();
      mqttClient.publish(TOPIC_STATUS,
        ok ? "Manual LoRa PING received a sensor reply" : "Manual LoRa PING retry window expired");
    } else {
      mqttClient.publish(TOPIC_STATUS, "Unknown ping command received; expected PING");
    }
  }
  else if (t == TOPIC_CONTROL) {
    if (msg.equalsIgnoreCase("ON")) {
      setLed(true);
      sendLightControlCmd(true);
    } else if (msg.equalsIgnoreCase("OFF")) {
      setLed(false);
      sendLightControlCmd(false);
    } else if (msg.equalsIgnoreCase("LIGHT ON") ||
               msg.equalsIgnoreCase("LIGHT_ON")) {
      sendLightControlCmd(true);
    } else if (msg.equalsIgnoreCase("LIGHT OFF") ||
               msg.equalsIgnoreCase("LIGHT_OFF")) {
      sendLightControlCmd(false);
    } else {
      mqttClient.publish(TOPIC_STATUS, "Unknown command received");
    }
  }
}

void publishHeartbeat() {
  if (!mqttClient.connected()) return;

  String msg = "Hello from ESP32 | uptime(s): ";
  msg += String(millis() / 1000);
  msg += " | LED: ";
  msg += (lightControlState ? "ON" : "OFF");

  mqttClient.publish(TOPIC_STATUS, msg.c_str());
  Serial.print("Heartbeat: ");
  Serial.println(msg);
}

void publishStatus(const String& msg) {
  Serial.print("STATUS: ");
  Serial.println(msg);

  if (mqttClient.connected()) {
    mqttClient.publish(TOPIC_STATUS, msg.c_str());
  }
}

void publishLightControlState() {
  String msg = "{";
  msg += "\"type\":\"LED\",";
  msg += "\"deviceId\":\"0x00000005\",";
  msg += "\"state\":\"";
  msg += lightControlState ? "ON" : "OFF";
  msg += "\"}";

  Serial.print("Light control state: ");
  Serial.println(msg);

  if (mqttClient.connected()) {
    mqttClient.publish(TOPIC_STATUS, msg.c_str());
  }
}

void setLed(bool on) {
  ledState = on;
  digitalWrite(LED_PIN, on ? HIGH : LOW);
  Serial.print("Gateway LED ");
  Serial.println(on ? "ON" : "OFF");
}

void handleSerialLightControlInput() {
  if (!Serial.available()) return;

  char c = Serial.read();

  // Manual light-node test shortcuts.
  // Remove this whole function, its prototype, and the call in loop()
  // when the automatic sensor-lux -> light-control path is fully verified.
  if (c == '1') {
    sendLightControlCmd(true);
  }
  else if (c == '0') {
    sendLightControlCmd(false);
  }
}


// Send a command line to the gateway slave over UART2.
// Example: sendToSlave("FREQ:120")
void sendToSlave(const String& cmd) {
  slaveSerial.print(cmd);
  slaveSerial.print('\n');
  Serial.print("-> Slave: ");
  Serial.println(cmd);
}

// Read and process any lines coming back from the gateway slave.
// Called every loop iteration; add application logic where marked.
void handleSlaveSerial() {
  while (slaveSerial.available()) {
    String line = slaveSerial.readStringUntil('\n');
    line.trim();
    if (line.length() == 0) continue;

    Serial.print("<- Slave: ");
    Serial.println(line);

    // TODO: process slave responses / forwarded sensor data here.
    // we need to parse the payload from the slave and publish it to MQTT just like we do for directly received LoRa packets
    //it needs to be in the same SensorData format, so we can reuse publishSensorData() and the MQTT topic structure. The slave can just forward the raw hex payload it receives from its RN2483, and we can parse it here. This way we can keep the slave's code very simple (just RN2483 config + receive + forward) and put all the logic in the main gateway code where we already have all the parsing/publishing functions.
    SensorData temp;
    if(parseSensorPayload(line, temp)){
      publishSensorData(temp, temp.lux < LIGHT_THRESHOLD_LUX);
    }
    
  }
}

bool initLoRa() {
  pinMode(RN2483_RST_PIN, OUTPUT);
  digitalWrite(RN2483_RST_PIN, HIGH);

  loraSerial.begin(LORA_BAUD_RATE, SERIAL_8N1, LORA_UART_RX_PIN, LORA_UART_TX_PIN);
  loraSerial.setTimeout(2000);

  // Reset the module after UART is up so the first command lands cleanly.
  digitalWrite(RN2483_RST_PIN, LOW);
  delay(200);
  digitalWrite(RN2483_RST_PIN, HIGH);
  delay(500);

  flushLoRaInput();

  String banner = readLoRaLine(500);
  if (banner.length()) {
    Serial.print("RN2483 banner: ");
    Serial.println(banner);
  }

  String ver = sendLoRaCommand("sys get ver", 1500);
  Serial.print("RN2483 version: ");
  Serial.println(ver);

  // mac pause first — we want raw LoRa, not LoRaWAN MAC
  String mp = sendLoRaCommand("mac pause", 2000);
  if (mp.length() == 0 || mp == "invalid_param") {
    Serial.println("mac pause failed");
    return false;
  }

  String cmds[] = {
    "radio set mod lora",
    String("radio set freq ")  + String(LORA_FREQ),
    String("radio set pwr ")   + String(LORA_PWR),
    String("radio set sf ")    + String(LORA_SF),
    String("radio set afcbw ") + String(LORA_AFCBW),
    String("radio set rxbw ")  + String(LORA_RXBW),
    String("radio set prlen ") + String(LORA_PRLEN),
    String("radio set crc ")   + String(LORA_CRC),
    String("radio set iqi ")   + String(LORA_IQI),
    String("radio set cr ")    + String(LORA_CR),
    String("radio set wdt ")   + String(LORA_WDT),
    String("radio set sync ")  + String(LORA_SYNC),
    String("radio set bw ")    + String(LORA_BW)
  };

  for (size_t i = 0; i < sizeof(cmds) / sizeof(cmds[0]); i++) {
    String r = sendLoRaCommand(cmds[i], 2000);
    if (r != "ok") {
      Serial.print("RN2483 rejected: ");
      Serial.print(cmds[i]);
      Serial.print("  -> ");
      Serial.println(r.length() ? r : "<timeout>");
      return false;
    }
  }

  loraReady = true;
  return true;
}

String sendLoRaCommand(const String& cmd, int timeoutMs) {
  Serial.print("RN2483 <= ");
  Serial.println(cmd);

  loraSerial.print(cmd);
  loraSerial.print("\r\n");

  String resp = readLoRaLine(timeoutMs);
  Serial.print("RN2483 => ");
  Serial.println(resp.length() ? resp : "<timeout>");
  return resp;
}

String readLoRaLine(int timeoutMs) {
  String line;
  unsigned long start = millis();
  while (millis() - start < (unsigned long)timeoutMs) {
    while (loraSerial.available()) {
      char c = (char)loraSerial.read();
      if (c == '\r') continue;
      if (c == '\n') { line.trim(); return line; }
      line += c;
    }
    delay(1);
  }
  line.trim();
  return line;
}

void flushLoRaInput() {
  while (loraSerial.available()) loraSerial.read();
}


void stopRx() {
  loraSerial.print("radio rxstop\r\n");
  // Read up to two short lines: the rxstop ack and any trailing
  // radio_rx / radio_err that was already in flight.
  for (int i = 0; i < 2; i++) {
    String line = readLoRaLine(300);
    if (line.length() == 0) break;
    Serial.print("RN2483 (drain) => ");
    Serial.println(line);
  }
}



bool sendPing(const char* reason) {
  if (!loraReady) {
    Serial.println("sendPing: LoRa not ready");
    return false;
  }

  Serial.print("Sending PING (");
  Serial.print(reason);
  Serial.println(")");

  uint8_t pingBuf[LORA_PING_BYTES];
  memcpy(pingBuf, LORA_PING_HEADER, 4);
  memcpy(pingBuf + 4, SHARED_KEY, 4);
  String pingHex = bytesToHex(pingBuf, LORA_PING_BYTES);

  String cmd = String("radio tx ") + pingHex;
  String firstReply = sendLoRaCommand(cmd, 2000);

  if (firstReply != "ok") {
    Serial.print("Ping rejected: ");
    Serial.println(firstReply);
    return false;
  }

  String txDone = readLoRaLine(10000);
  Serial.print("RN2483 => ");
  Serial.println(txDone.length() ? txDone : "<timeout>");

  if (txDone != "radio_tx_ok") {
    Serial.println("TX did not complete cleanly.");
    return false;
  }
  return waitForSensorReply(POST_PING_WAIT_MS);
}
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

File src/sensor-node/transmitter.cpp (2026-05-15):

/*

  Board: ESP32 (DevKit / WROOM) with RN2483 LoRa module
  Role:  Sensor node. Wakes from deep sleep, listens for the gateway's PING,
         transmits a 13-byte sensor payload, listens briefly for a light
         command, then goes back to sleep.

  Important: ESP32 cannot listen on the radio while it is in deep sleep —
  deep sleep powers down the CPU. So the cycle is:
    wake -> RX ping -> TX data -> RX command (short window) -> deep sleep.


  Test:
    1. Flash, open Serial Monitor at 115200.
    2. Have the gateway running. Within PING_WAIT_MS the node should
       receive the ping, transmit a real sensor reading, and either turn its
       LED on or stay dark depending on the lux value.
    3. Then it sleeps for the gateway-provided RTC sleep duration and the cycle repeats.


*/

#include <Arduino.h>
#include <HardwareSerial.h>
#include <Wire.h>
#include <Adafruit_GFX.h>
#include <Adafruit_SH110X.h>
#include <DHT.h>
#include <esp_sleep.h>

// ---------- Pins ----------
#define LED_PIN          2
// ---------------------- PINS UPDATED we are using pedros setup for easier use of PCB but update on everyone elses
#define LORA_UART_RX_PIN 16    // ESP32 GPIO16 -> RN2483 TX
#define LORA_UART_TX_PIN 17    // ESP32 GPIO17 -> RN2483 RX

#define RN2483_RST_PIN   14
#define I2C_SDA          21
#define I2C_SCL          22

// ---------- Sensor pins ----------
#define LIGHT_PIN        34    // KY-018/photoresistor analog output
#define DHTPIN           4
#define DHTTYPE          DHT22
#define SOIL_PIN         35    

// ---------- LoRa radio settings (must match gateway) ----------
#define LORA_BAUD_RATE   57600UL
#define LORA_FREQ        868100000UL
#define LORA_PWR         14
#define LORA_SF          "sf12"
#define LORA_AFCBW       "41.7"
#define LORA_RXBW        125
#define LORA_PRLEN       8
#define LORA_CRC         "on"
#define LORA_IQI         "off"
#define LORA_CR          "4/5"
#define LORA_SYNC        "12"
#define LORA_BW          125
#define LORA_WDT         60000UL


#define DEVICE_ID                0x01AABBCC   // top byte 0x01 = sensor node
#define SENSOR_PAYLOAD_BYTES     13
#define LIGHT_CMD_BYTES          8
#define LIGHT_CMD_HEX_CHARS      16

// ---------- Shared secret ----------
static const uint8_t SHARED_KEY[4] = { 0xA3, 0x7F, 0x2C, 0x91 };
static const uint8_t LORA_PING_HEADER[4] = { 0x50, 0x49, 0x4E, 0x47 };  // "PING"

#define PING_WAIT_MS             12000UL    // listen this long after sync is established
#define FIRST_SYNC_PING_WAIT_MS  130000UL   
#define POST_TX_RX_MS            8000UL     
#define DEFAULT_SLEEP_S          115UL      

HardwareSerial loraSerial(1);
DHT dht(DHTPIN, DHTTYPE);
bool loraReady = false;
RTC_DATA_ATTR uint32_t rtcSleepSeconds = DEFAULT_SLEEP_S;
RTC_DATA_ATTR bool rtcSyncedWithGateway = false;

#define SCREEN_WIDTH 128
#define SCREEN_HEIGHT 64
#define OLED_RESET -1
Adafruit_SH1106G display = Adafruit_SH1106G(SCREEN_WIDTH, SCREEN_HEIGHT, &Wire, OLED_RESET);
bool oledConnected = false;


void xorWithKey(uint8_t* data, size_t len) {
  for (size_t i = 0; i < len; i++) {
    data[i] ^= SHARED_KEY[i % 4];
  }
}

struct SensorReading {
  int16_t  tempTenthsC;     // tenths of °C
  uint8_t  humidity;        // %
  uint16_t lux;
  uint16_t soilMoistureRaw; // ADC
  uint8_t  waterLeak;       // 0 = dry, 1 = leak
  uint8_t  battery;         // %
  const char* label;        // for debug logging
};

// ---------- Forward decls ----------
bool   initLoRa();
String sendLoRaCommand(const String& cmd, int timeoutMs);
String readLoRaLine(int timeoutMs);
void   flushLoRaInput();
void   stopRx();

bool receivePacket(int timeoutMs, String& payloadHexOut);
bool sendPayload(const String& hex);

bool isValidPing(const String& hex);
bool waitForValidPing(int timeoutMs);

SensorReading readSensorData();
void initOled();
void updateUi(const SensorReading& r, const char* stateText);
void buildSensorPayload(const SensorReading& r, uint8_t* out13);
bool parseLightCommand(const String& hex,
                       uint32_t& targetIdOut,
                       uint16_t& desiredLuxOut,
                       uint16_t& nextSleepSOut);

bool   hexToBytes(const String& hexStr, uint8_t* out, size_t outLen);
String bytesToHex(const uint8_t* data, size_t len);
int    hexNibble(char c);
void xorWithKey(uint8_t* data, size_t len);

void goToDeepSleep();


bool isValidPing(const String& hex) {
  if (hex.length() < 16) return false;
  uint8_t b[8];
  if (!hexToBytes(hex.substring(0, 16), b, 8)) return false;
  if (b[0] != LORA_PING_HEADER[0] || b[1] != LORA_PING_HEADER[1] ||
      b[2] != LORA_PING_HEADER[2] || b[3] != LORA_PING_HEADER[3]) return false;
  for (int i = 0; i < 4; i++) {
    if (b[4 + i] != SHARED_KEY[i]) return false;
  }
  return true;
}

bool waitForValidPing(int timeoutMs) {
  unsigned long deadline = millis() + (unsigned long)timeoutMs;
  while (millis() < deadline) {
    long remaining = (long)(deadline - millis());
    if (remaining <= 100) break;
    String hex;
    if (!receivePacket((int)remaining, hex)) {
      Serial.println("RX error; retrying within window.");
      continue;
    }
    if (isValidPing(hex)) {
      Serial.println("Valid PING received.");
      return true;
    }
    Serial.print("Rejected packet (key mismatch or not PING): ");
    Serial.println(hex);
  }
  return false;
}
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

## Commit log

2026-04-09 docs: initial PCB documentation structure — IoT Greenhouse Monitor Group 5
2026-05-08 added gateway integration and sensor node
2026-05-11 fix: align transmitter sleep cycle with gateway ping interval
    [transmitter.cpp]
2026-05-11 fix: use long for remaining time, retry on transient RX error in waitForValidPing
    [transmitter.cpp]
2026-05-11 feat: gateway rejects sensor payloads from unapproved device IDs
2026-05-11 feat: XOR-encrypt sensor payload before LoRa transmission
2026-05-11 feat: XOR-decrypt received sensor payload before parsing
2026-05-12 Implement gateway-led sleep sync for LoRa nodes
2026-05-14 pin fix
2026-05-14 OLED fix in transmiter
    [transmitter.cpp]
2026-05-24 Remove obsolete test sketches and main screen UI code for the greenhouse project. This includes the DHT22 test, device ID retrieval, LoRa communication tests, and OLED display tests. The removal stre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
2026-05-24 Kikcad cleanup
    [Iot.kicad_pcb, Iot.kicad_sch, iotcase.f3d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]
